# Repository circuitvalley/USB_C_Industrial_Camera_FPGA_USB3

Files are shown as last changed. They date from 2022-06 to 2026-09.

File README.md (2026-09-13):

### USB C industrial camera with Interchangeable C mount Lens, Interchangeable MIPI Sensor with Lattice Crosslink NX FPGA Cypress FX3 USB 3.0 controller

> [!TIP]
> **New Version CHC5 Open Source Camera is available.**

<a href="https://github.com/circuitvalley/CHC5_Open_Camera">
OpenSourceCamera
</a>

New CHC5 Github  https://github.com/circuitvalley/CHC5_Open_Camera

## FPGA ISP Pipeline Specifications
MPI CSI receiver ISP has No virtual restriction on supported frame rate or resolution. Tested more than 4K with IMX477 4056x3040. Can do 8K with around 30FPS or even higher than that as long as FPGA is fast enough for needed frame rate and FPGA/Board has enough memory to be able to store minimum 4 Line worth of pixels. Output Clock is independent of MIPI clock.
Easily Portable code to Xilinx or any other FPGA, No Vendor specific components has been used except for the PHY itself which can be replaced by other vendor's DDR phy and Embedded Block RAM. Only Debayer/Demosaic and Output reformatter need Block RAM. Block ram can also be replaced vendor's RAM.
Auto detection of RAW pixel width supporting different camera sensors and sensor modes without FPGA reconfiguration. 

Speed
------------
- Supports MIPI bus clock 900Mbitsps Per lane with upto 4 Lanes, Total 3.6Gbitsps Sensor bit stream, Has been Tested upto 900Mbitsps with 8x Gear.</br>
- Pixel Processing pipeline with 2,4 or 8 Pixel per clock can reach more than 110Mhz with Lattice Crosslink-NX LIFCL-40 High Speed, So basically Can process upto 880 MegaPixels per second. With this can reach Around 120FPS with 4K resolution and around 30 FPS with 8K. Or even 3000 FPS with 640 x 480 as long as Camera and MIPI Wire allows. With Different Faster FPGA speed will be more.</br>
- FPGA Oputput Pipeline is decoupled from MIPI clock, runs on output clock, It feeds into Cypress FX3 32bit GPIF can do Max 160Mhz. Cyress FX3's specs limits max GPIF clock to 100Mhz.</br>

Configurability
------------
- **Selectable max RAW pixel width**</br>
FPGA Design is configurable with parameters to support pixel depth from RAW10 to RAW14 or Virtually  any bit depth even 16bit RAW when it becomes a MIPI Specs. Parameter specify maximum pixel width that is supported while module auto detect package type at runtime with RAW14 selected as max pixel width, RAW10, RAW12 and RAW14 will be automatically detected and processed</br>
- **Selectable number of MIPI lanes**</br>
With just definition of Parameter value number of lane is also configurable between 2 or 4 MIPI lanes.</br>
- **Selectable Pipeline Size**</br>
Pipeline is Configurable with a parameter to Process 2,4 or 8 Pixel.  2 Pixel Per Clock is only available with 2 Lane MIPI, while 8 Pixel Per Clock is only available with 4 Lanes.</br>
- **Selectable MIPI Gear Ratio**</br>
User can select weather to operate MIPI/DDR phy in 16x or 8x Gear ratio. Most DDR/MIPI phy supports 8x Gear while few do support 16x gear.</br>
Block RAM and DDR PHY IPs need to be manually regenerated if Gear, pixel width , lane or PPC is changed.</br>
- **Selectable MIPI continuous clock mode**</br>
User and select between MIPI clock lp based Frame sync or Frame start and frame stop packt based frame sync. Some MIPI cameras do not support going to LP mode while frame blank occur, With this option user can enable Frame Start and Frame stop detection, to have a frame sync.
- **Selectable ROM based Sample Generator**</br>
For ISP debuging ROM based sample generator can be activated. Two ROM lines are there have both even and odd line to full image test.

Tests 
------------
IMX477
------------
- 4 Lane 12 bit IMX477</br>
4056x3040  15 FPS Full Sensor</br>
2028x1520  60 FPS Full Sensor Binned 2x2</br> 
2028x1080  100 FPS</br>

- 4 Lane 10 bit IMX477</br>
1332x990  150 FPS Binned 4x4</br>
640x480   400 FPS Binned 4x4</br>
640x128   2400 FPS Binned 4x4</br>

- 2 Lane 12 bit IMX477</br>
4056x3040  10 FPS Full Sensor</br>
2028x1520  35 FPS Full Sensor Binned 2x2</br> 
2028x1080  50 FPS</br>

- 2 Lane 10 bit IMX477</br>
1332x990  100 FPS Binned 4x4</br>
640x480   200 FPS Binned 4x4</br>
640x128   1200 FPS Binned 4x4</br>

IMX219
------------
- 4 Lane 10 bit IMX219</br>
3280x2464 30 FPS</br>
1280x720  240 FPS</br>
1920x1080 120 FPS</br>
640x480   400 FPS</br>
640x128   1300 FPS</br>
640x80    2000 FPS</br>

- 2 Lane 10 bit IMX219</br>
3280x2464 15 FPS</br>
1280x720  60 FPS</br>
1280x720  120 FPS</br>
1920x1080 60 FPS</br>
640x480   30 FPS</br>
640x480   200 FPS</br>
640x128   600 FPS</br>
640x80    900 FPS</br>

IMX290/IMX327/IMX462
------------
- 4 Lane 12 bit</br>
1280x720  120 FPS</br>
1920x1080 120 FPS</br>

- 2 Lane 12 bit</br>
1280x720  60 FPS</br>
1920x1080 60 FPS</br>

<a href="https://www.youtube.com/watch?v=dwXs9RB6uD0">
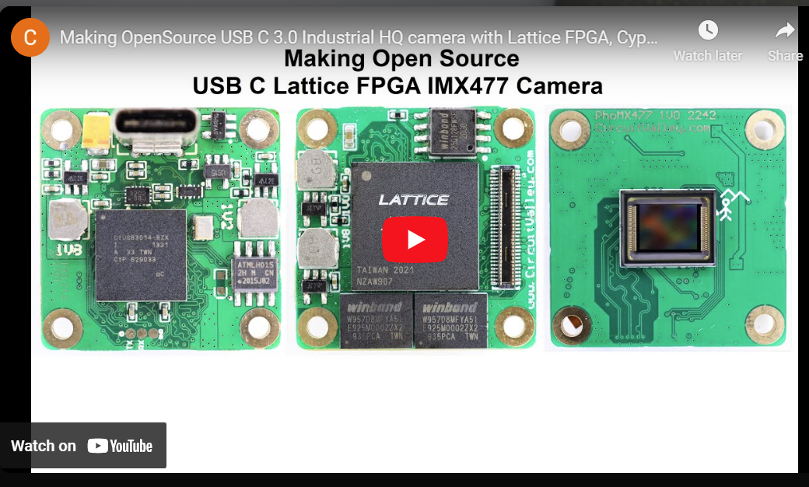
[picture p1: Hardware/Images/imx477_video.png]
IMX219

</a>

#### Project Blog post 
https://www.circuitvalley.com/2022/06/pensource-usb-c-industrial-camera-c-mount-fpga-imx-mipi-usb-3-crosslinknx.html

Shield: [][cc-by]

This work is licensed under a [Creative Commons Attribution 4.0 International
License][cc-by].

[][cc-by]

[cc-by]: http://creativecommons.org/licenses/by/4.0/
[cc-by-image]: https://i.creativecommons.org/l/by/4.0/88x31.png
[cc-by-shield]: https://img.shields.io/badge/License-CC%20BY%204.0-lightgrey.svg



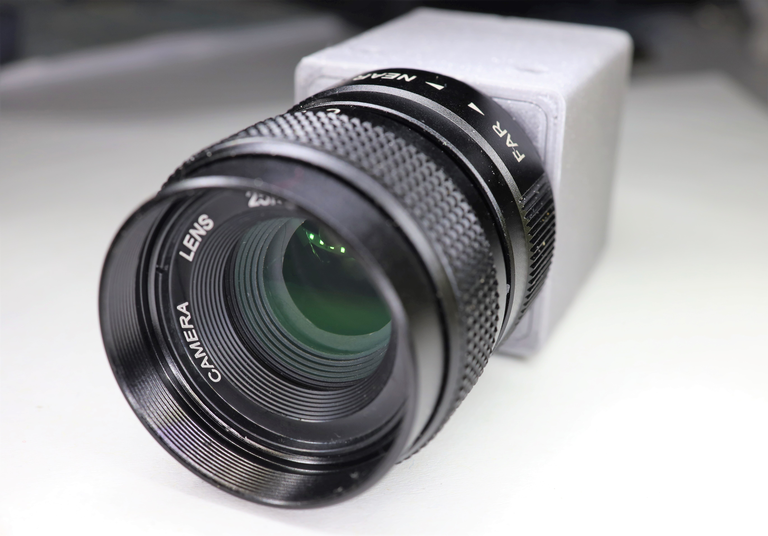
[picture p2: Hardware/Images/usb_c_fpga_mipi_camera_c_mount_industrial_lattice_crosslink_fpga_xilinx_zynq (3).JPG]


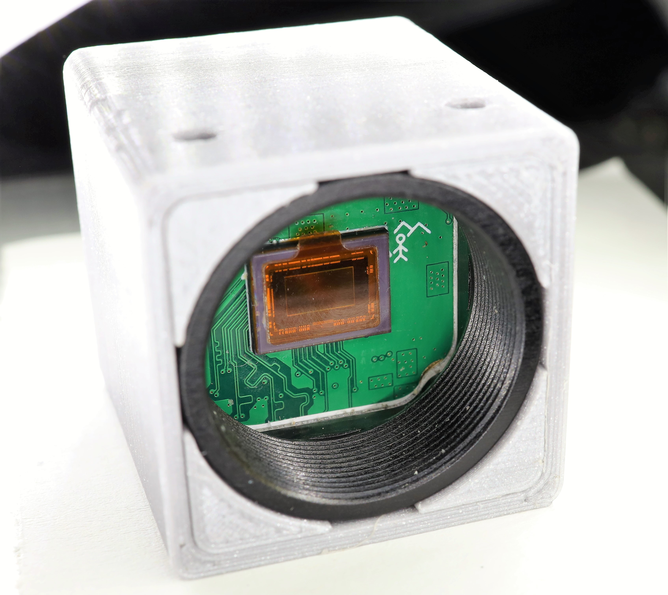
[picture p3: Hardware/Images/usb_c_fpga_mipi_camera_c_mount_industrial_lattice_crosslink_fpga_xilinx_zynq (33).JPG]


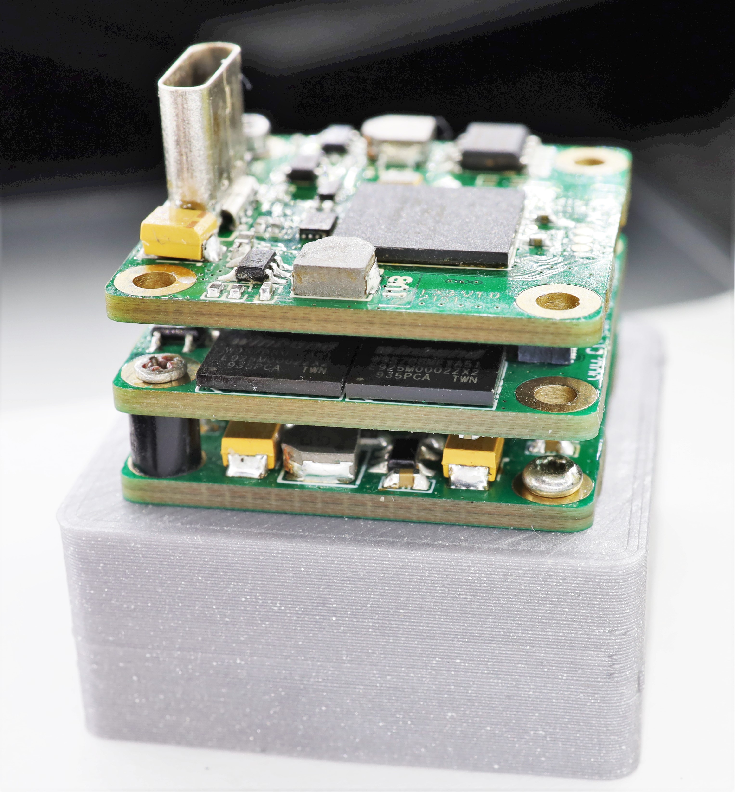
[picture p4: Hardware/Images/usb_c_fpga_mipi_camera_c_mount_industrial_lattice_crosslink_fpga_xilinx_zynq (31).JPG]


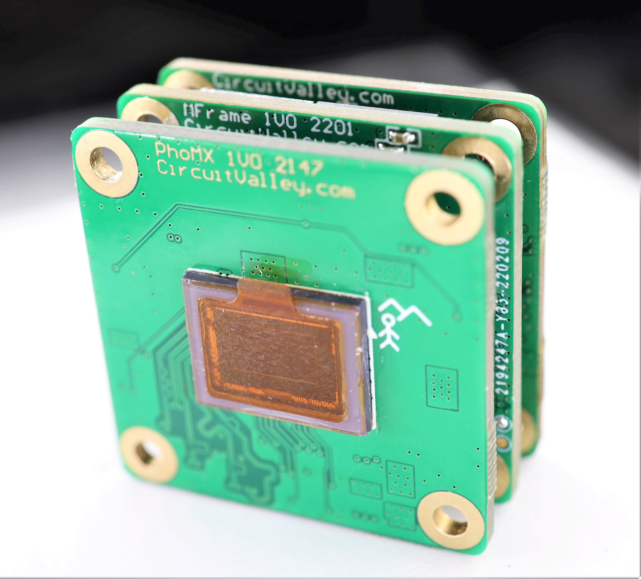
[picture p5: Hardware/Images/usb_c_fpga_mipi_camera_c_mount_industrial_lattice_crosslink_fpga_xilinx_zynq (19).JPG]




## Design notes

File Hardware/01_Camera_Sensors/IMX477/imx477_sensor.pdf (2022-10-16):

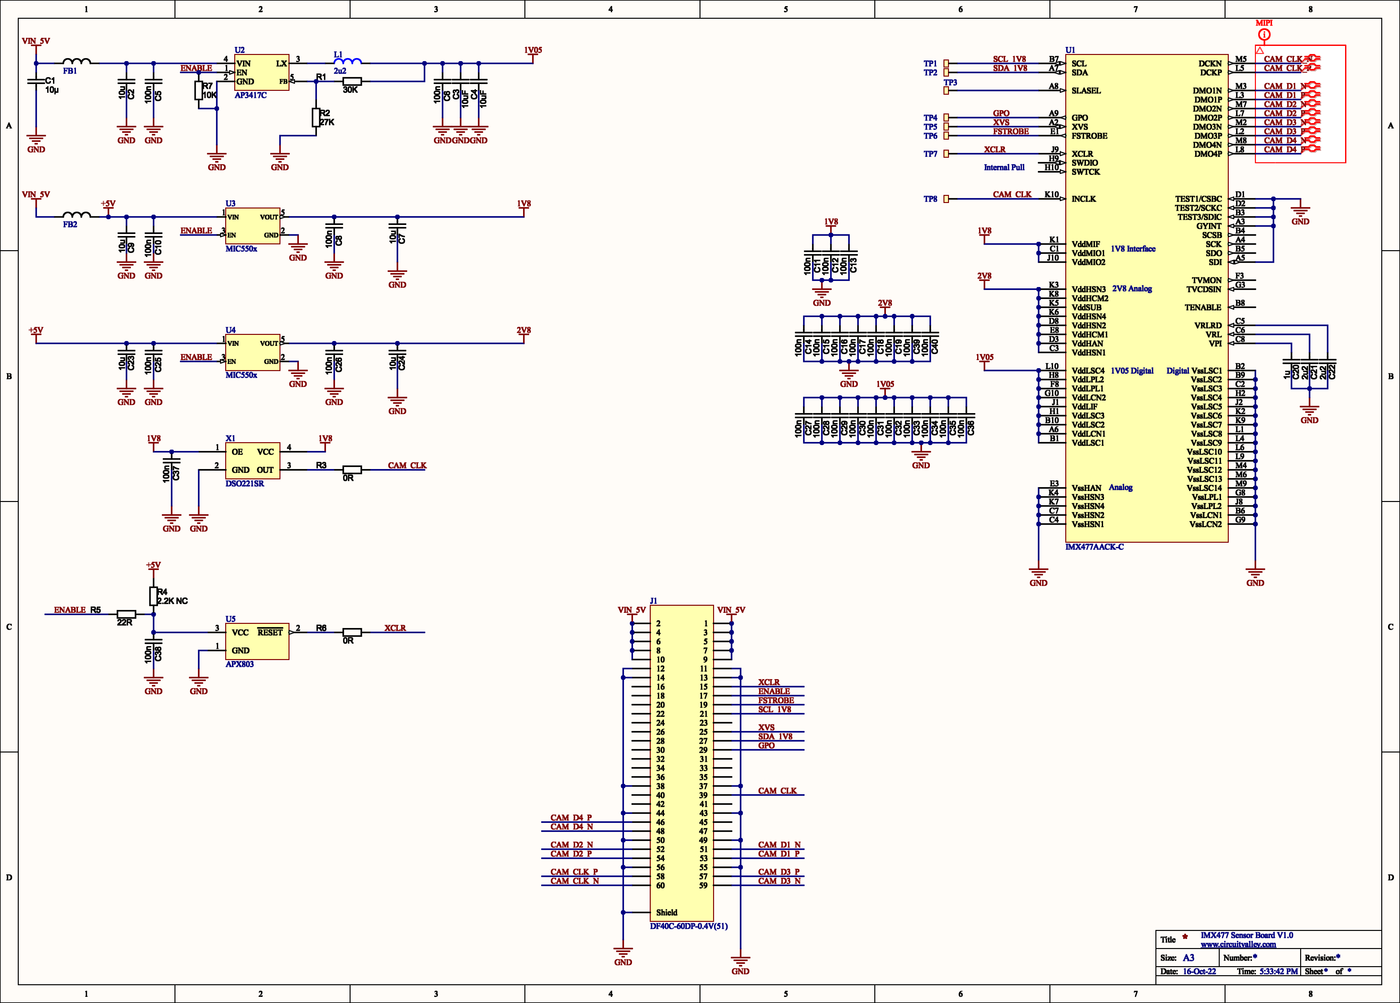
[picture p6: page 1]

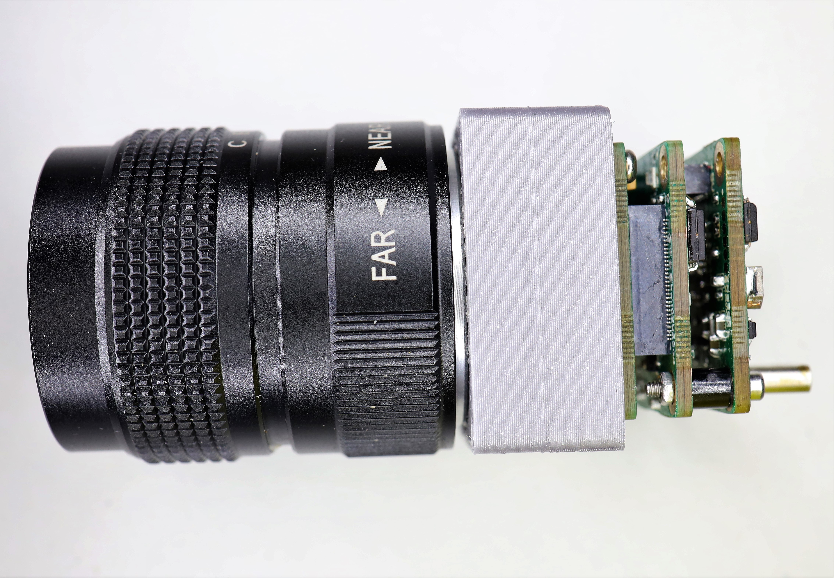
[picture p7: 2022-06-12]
Hardware/Images/usb_c_fpga_mipi_camera_c_mount_industrial_lattice_crosslink_fpga_xilinx_zynq (6).JPG

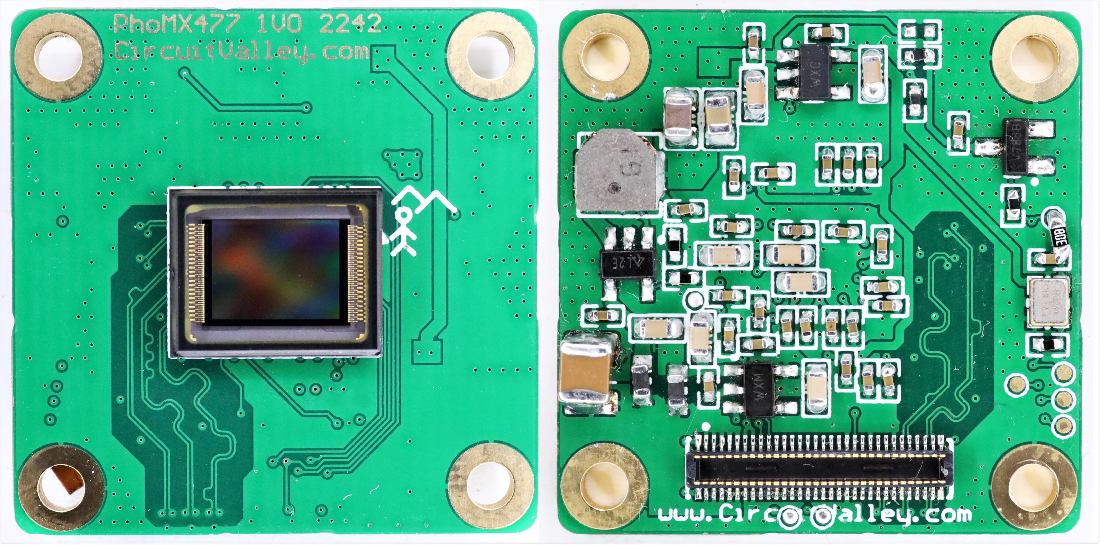
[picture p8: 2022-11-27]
Hardware/Images/custom IMX477 Sensor with FPGA.JPG

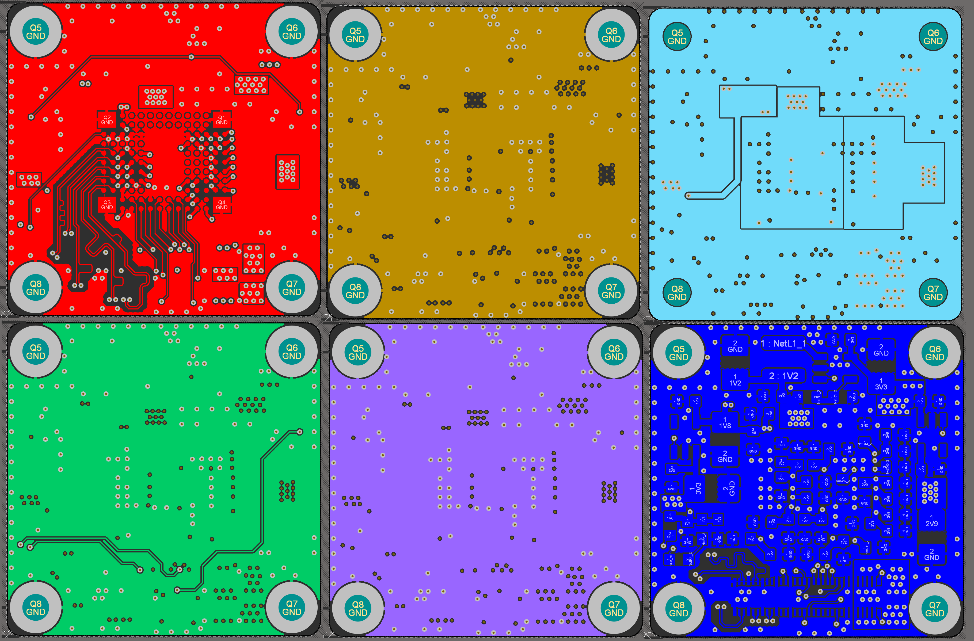
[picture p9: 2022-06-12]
Hardware/Images/IMX290_sensor_PCB.png

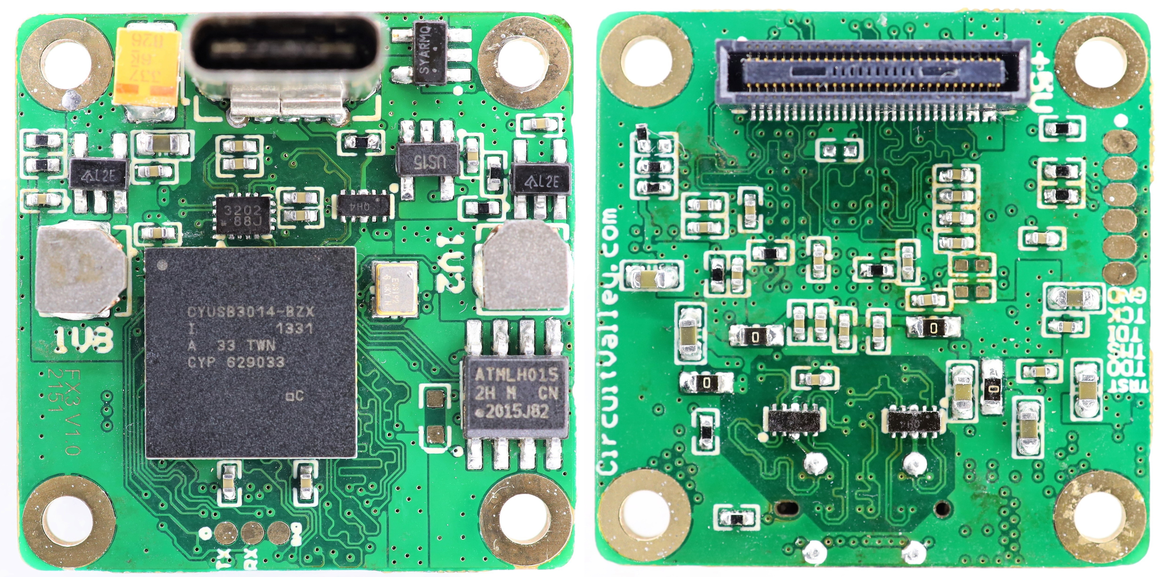
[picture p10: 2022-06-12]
Hardware/Images/usb_c_fpga_mipi_camera_c_mount_industrial_lattice_crosslink_fpga_xilinx_zynq (12)2.JPG

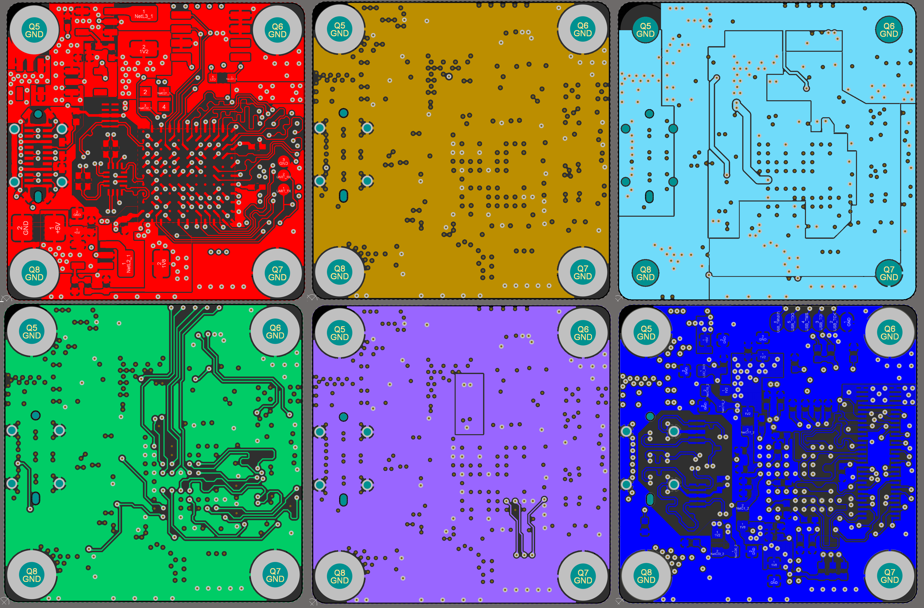
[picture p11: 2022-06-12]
Hardware/Images/fx3_PCB.png

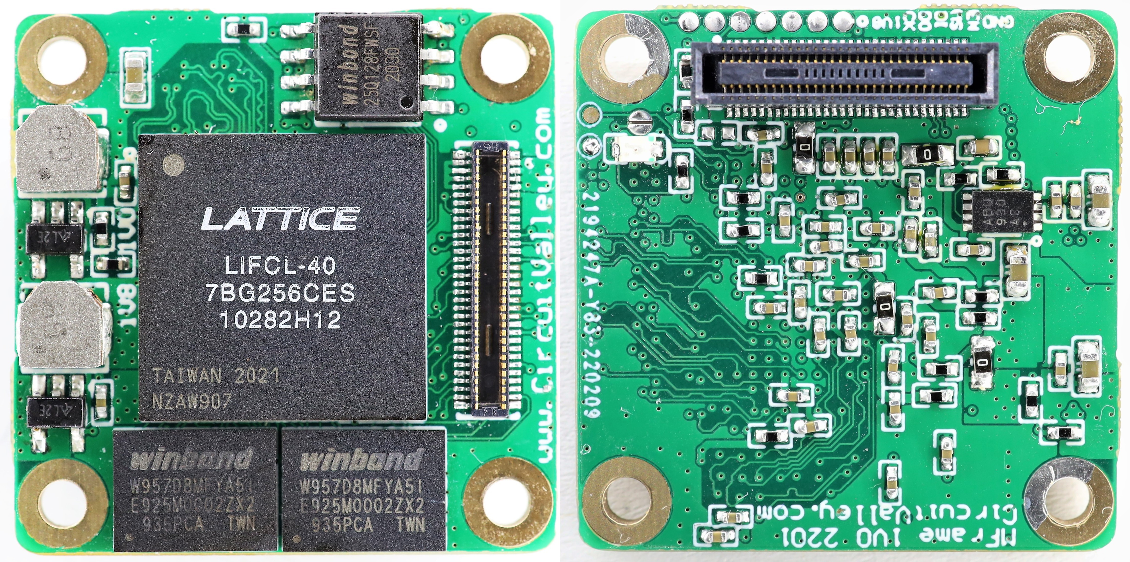
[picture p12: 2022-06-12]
Hardware/Images/usb_c_fpga_mipi_camera_c_mount_industrial_lattice_crosslink_fpga_xilinx_zynq (14)1.JPG

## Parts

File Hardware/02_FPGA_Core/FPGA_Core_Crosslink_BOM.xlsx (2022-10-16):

Comment | Description | Designator | Footprint | Quantity | QTY1 | QTY 10 | QTY100 | QTY500 | Price 1 | Price 10 | Price 100 | Price 500
100n | Capacitor SMD Cer 100nF 10% 16V X7R 0402 | C1, C3, C4, C5, C6, C7, C8, C9, C11, C12, C13, C14, C15, C16, C17, C18, C19, C20, C21, C22, C23, C24, C26, C27, C28, C29, C30, C31, C32, C33, C38, C39, C40, C42, C43, C44, C45, C? | CAPC1005N | 38 | 0.1 | 0.025 | 0.021 | 0.015 | 3.8 | 0.95 | 0.798 | 0.57
1uf | Capacitor SMD Cer 10nF 10% 16V X7R 0402 | C2 | CAPC1005N | 1 | 0.1 | 0.041 | 0.033 | 0.024 | 0.1 | 0.041 | 0.033 | 0.024
10uF | Capacitor SMD Cer 10uf 5% 50V NP0 0603 | C34, C35, C36, C37 | CAPC1608N | 4 | 0.29 | 0.131 | 0.111 | 0.079 | 1.16 | 0.524 | 0.444 | 0.316
Ferrite |  | FB1, FB2, FB3, FB4 | INDC1608N | 4 | 0.1 | 0.068 | 0.037 | 0.034 | 0.4 | 0.272 | 0.148 | 0.136
DF40C-60DP-0.4V(51) | Samtec 0.5mm 60 pin Connector | J1 | DF40C-60DP-0.4V | 1 | 1.4 | 1.12 | 1.07 | 0.871 | 1.4 | 1.12 | 1.07 | 0.871
SMD Jumper | SMD Jumper | J2 | SMD_Jumper | 1 | 0 | 0 | 0 | 0 | 0 | 0 | 0 | 0
DF40HC(4.0)-60DS-0.4V(51) | Hiros 60 pin Connector | J3 | DF40HC(4.0)-60DS-0.4V(51) | 1 | 1.81 | 1.51 | 1.41 | 1.18 | 1.81 | 1.51 | 1.41 | 1.18
2u2 |  | L2, L3 | FDSD0420-H-2R2M | 2 | 0.65 | 0.527 | 0.415 | 0.349 | 1.3 | 1.054 | 0.83 | 0.698
TestPoint | SMD Test Point | L4, L7 | SMD_test_point | 2 |  |  |  |  | 0 | 0 | 0 | 0
Red | LED 0603 SMD Hyper Red 630nm 220mcd 20mA | LED2 | LED-0603-RED | 1 | 0.16 | 0.151 | 0.142 | 0.105 | 0.16 | 0.151 | 0.142 | 0.105
Header |  | P1 | SMD_Solder_points_1.27_x7 | 1 | 0 | 0 | 0 | 0 | 0 | 0 | 0 | 0
Thick Film | Resistor SMD chip 0.063W 5% 0402 | R1, R2, R3, R4, R5, R6, R7, R8, R9, R12, R13, R15, R16, R23, R24, R25, R26, R27, R? | RESC1005N | 19 | 0.1 | 0.07 | 0.029 | 0.013 | 1.9 | 1.33 | 0.551 | 0.247
LIFCL-40-9BG256C | FPGA CorsslinkNX LIFCL-40-9BG256C | U1 | Lattice_256_CABGA | 1 | 65.95 | 57.42 | 55.28 | 55.28 | 65.95 | 57.42 | 55.28 | 55.28
W957D8MFYA5I | HyperRAM 16Mx8 | U2, U21 | TFBGA24 | 2 | 3.93 | 3.11 | 3.1 | 2.99 | 7.86 | 6.22 | 6.2 | 5.98
MCP1725-ADJE/MC | LDO | U3 | DFN8_3x2 | 1 | 0.72 | 0.711 | 0.541 | 0.54 | 0.72 | 0.711 | 0.541 | 0.54
SST26WF064C / MX25U12832F | Flash 128Mbit for Lattice FPGA | U4 | SOP8 | 1 | 2.07 | 1.85 | 1.8 | 1.8 | 2.07 | 1.85 | 1.8 | 1.8
AP3417C |  | U7, U11 | SOT23-5 | 2 | 0.5 | 0.274 | 0.185 | 0.157 | 1 | 0.548 | 0.37 | 0.314
PCB |  |  |  | 1 | 10 | 5 | 1 | 0.29 | 10 | 5 | 1 | 0.29
 |  |  |  |  |  |  |  |  | 99.63 | 78.701 | 70.617 | 68.351
 |  |  |  |  | These are mouser price EUR, So improvements possible.

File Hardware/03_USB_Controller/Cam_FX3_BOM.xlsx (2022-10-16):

Comment | Description | Designator | Footprint | Quantity | QTY1 | QTY 10 | QTY100 | QTY500 | Price 1 | Price 10 | Price 100 | Price 500
100n | Capacitor SMD Cer 100nF 10% 16V X7R 0402 | C1, C2, C3, C4, C5, C6, C7, C8, C9, C10, C11, C12, C13, C14, C15, C17, C19, C20, C21, C22, C23, C24, C26, C27, C28, C29, C30, C42, C87, C88, C89, C90 | CAPC1005N | 32 | 0.1 | 0.025 | 0.021 | 0.015 | 3.2 | 0.8 | 0.672 | 0.48
10nF | Capacitor SMD Cer 10nF 10% 16V X7R 0402 | C18 | CAPC1005N | 1 | 0.1 | 0.041 | 0.033 | 0.024 | 0.1 | 0.041 | 0.033 | 0.024
10µ | Capacitor SMD Tantalum 10uF 20% 6.3V 1210 | C25 | CAPMP3528X210N | 1 | 0.37 | 0.277 | 0.198 | 0.131 | 0.37 | 0.277 | 0.198 | 0.131
10uF | Capacitor SMD Cer 560pF 5% 50V NP0 0603 | C34, C35, C36, C37, C38, C39, C40 | CAPC1608N | 7 | 0.29 | 0.131 | 0.111 | 0.079 | 2.03 | 0.917 | 0.777 | 0.553
Ferrite |  | FB1, FB2, FB3, FB4 | INDC1608N | 4 | 0.1 | 0.068 | 0.037 | 0.034 | 0.4 | 0.272 | 0.148 | 0.136
DF40HC(4.0)-60DS-0.4V(51) | Hiros 60 pin Connector | J1 | DF40HC(4.0)-60DS-0.4V(51) | 1 | 1.81 | 1.51 | 1.41 | 1.18 | 1.81 | 1.51 | 1.41 | 1.18
USB C Connector | USB C connector | J2 | 10132328-10001LF | 1 | 3.64 | 3.29 | 2.92 | 2.55 | 3.64 | 3.29 | 2.92 | 2.55
2u2 |  | L2, L3 | FDSD0420-H-2R2M | 2 | 0.65 | 0.527 | 0.415 | 0.349 | 1.3 | 1.054 | 0.83 | 0.698
Red | LED 0603 SMD Hyper Red 630nm 220mcd 20mA | LED1 | LED-0603-RED | 1 | 0.16 | 0.151 | 0.142 | 0.105 | 0.16 | 0.151 | 0.142 | 0.105
Header 6 | Header, 6-Pin | P2 | SMD_Solder_points_1.27 | 1
Header 3 | Header, 3-Pin | P4 | SMD_3Solder_points_1.27 | 1
6.04K | Resistor SMD chip 3.3k Ohm 0.063W 5% 0402 | R1, R6 | RESC1005N | 2 | 0.1 | 0.07 | 0.029 | 0.013 | 0.2 | 0.14 | 0.058 | 0.026
Thick Film | Resistor SMD chip 3.3k Ohm 0.063W 5% 0402 | R2, R3, R4, R5, R8, R9, R10, R11, R12, R13, R14, R15, R16, R17 | RESC1005N | 14 | 0.1 | 0.07 | 0.029 | 0.013 | 1.4 | 0.98 | 0.406 | 0.182
AP3417C |  | U7, U11 | SOT23-5 | 2 | 0.5 | 0.274 | 0.185 | 0.157 | 1 | 0.548 | 0.37 | 0.314
NCP360SNT1G | USB Overvoltage Protection | U12 | SOT23-5 | 1 | 0.87 | 0.763 | 0.593 | 0.463 | 0.87 | 0.763 | 0.593 | 0.463
CYUSB3014-BZXC | EZ-USB(R) FX3: SuperSpeed USB Controller, 512 KB, 60 I/Os, 0 to 70 degC, 121-Pin FBGA (BZX121) | U13 | CYP-BZX121 | 1 | 38.88 | 35.878 | 30 | 29 | 38.88 | 35.878 | 30 | 29
SP3010-04UTG | ESD Protection | U14, U15, U18 | uDFN-10 | 3 | 0.87 | 0.781 | 0.609 | 0.397 | 2.61 | 2.343 | 1.827 | 1.191
AT24CM02 | 2Mbit I2C EEPROM | U16 | SOIC8 | 1 | 3.44 | 3.13 | 3.06 | 2.73 | 3.44 | 3.13 | 3.06 | 2.73
HD3SS3202 | USB 3.0 Mux | U17 | UQFN-16 | 1 | 1.35 | 1.22 | 1.16 | 0.949 | 1.35 | 1.22 | 1.16 | 0.949
MIC550x |  | U20 | SOT23-5 | 1 | 0.16 | 0.159 | 0.12 | 0.12 | 0.16 | 0.159 | 0.12 | 0.12
ECS-192-7-36B-CKY-TR | Crystal Oscillator | X1 | Active Oscillator 2520 | 1 | 0.5 | 0.383 | 0.334 | 0.316 | 0.5 | 0.383 | 0.334 | 0.316
PCB |  |  |  | 1 | 10 | 5 | 1 | 0.29 | 10 | 5 | 1 | 0.29
 |  |  |  |  |  |  |  |  | 60.57 | 50.695 | 39.07 | 35.686
 |  |  |  |  | These are mouser price in EUR , So improvements possible.

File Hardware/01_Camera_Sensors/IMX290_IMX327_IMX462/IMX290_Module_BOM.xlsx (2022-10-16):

Comment | Description | Designator | Footprint | LibRef | Quantity | Qty1 | Qty10 | QTY100 | QTY500 | Price 1 | Price 10 | Price 100 | Price 500
10u | Capacitor SMD Tantalum 10uF 20% 6.3V 1210 | C1, C2, C6, C7, C11 | CAPMP3528X210N | CAPT_47u_1210_6V3 | 5 | 0.37 | 0.277 | 0.198 | 0.131 | 1.85 | 1.385 | 0.99 | 0.655
100n | Capacitor SMD Cer 100nF 5% 50V NP0 0603 | C3, C4, C5, C8, C9, C12, C13, C14, C15, C16, C17, C18, C19, C20, C21, C22, C23, C24, C25, C26 | CAPC1608N | CAPC_10p_0603_NP0_1%_50V | 20 | 0.1 | 0.041 | 0.033 | 0.024 | 2 | 0.82 | 0.66 | 0.48
10u | Capacitor SMD Cer 10uF 5% 50V NP0 0603 | C10, C29, C31, C32, C33, C34, C35, C36, C37, C39, C40 | CAPC1608N | CAPC_10p_0603_NP0_1%_50V | 11 | 0.1 | 0.041 | 0.033 | 0.024 | 1.1 | 0.451 | 0.363 | 0.264
10n | Capacitor SMD Cer 10nF 5% 50V NP0 0603 | C27 | CAPC1608N | CAPC_10p_0603_NP0_1%_50V | 1 | 0.1 | 0.041 | 0.033 | 0.024 | 0.1 | 0.041 | 0.033 | 0.024
0.22uf | Capacitor SMD Cer 220nF 5% 50V NP0 0603 | C41 | CAPC1608N | CAPC_10p_0603_NP0_1%_50V | 1 | 0.1 | 0.041 | 0.033 | 0.024 | 0.1 | 0.041 | 0.033 | 0.024
1uf | Capacitor SMD Cer 1uF 5% 50V NP0 0603 | C42, C43, C44 | CAPC1608N | CAPC_10p_0603_NP0_1%_50V | 3 | 0.1 | 0.041 | 0.033 | 0.024 | 0.3 | 0.123 | 0.099 | 0.072
DF40C-60DP-0.4V(51) | Samtec 0.5mm 60 pin Connector | J1 | DF40C-60DP-0.4V | LSHM-130-xx | 1 | 1.4 | 1.12 | 1.07 | 0.871 | 1.4 | 1.12 | 1.07 | 0.871
2u2 |  | L1 | TAIYO_NRS4018T2R2MDGJ | inductor_smd | 1 | 0.65 | 0.527 | 0.415 | 0.349 | 0.65 | 0.527 | 0.415 | 0.349
Thick Film | Resistor SMD chip 0.0 Ohm 0.1W 0603 | R1, R2, R3, R4 | RESC1608N_ZERO | RES_0R_0603 | 4 | 0.1 | 0.07 | 0.029 | 0.013 | 0.4 | 0.28 | 0.116 | 0.052
IMX290LQR-C | Sony Color Image senosr | U1 | IMX290LQR-C | IMX290LQR-C | 1 | 20 | 20 | 20 | 20 | 20 | 20 | 20 | 20
AP3417C |  | U2 | SOT23-5 | AP3417C | 1 | 0.5 | 0.274 | 0.185 | 0.157 | 0.5 | 0.274 | 0.185 | 0.157
MIC550x |  | U3, U4 | SOT23-5 | MIC550x | 2 | 0.16 | 0.159 | 0.12 | 0.12 | 0.32 | 0.318 | 0.24 | 0.24
DSO221SR | Active Oscillator_2520 | X1 | Active Oscillator 2520 | Oscillator_2520 | 1 | 2.03 | 1.94 | 1.63 | 1.63 | 2.03 | 1.94 | 1.63 | 1.63
PCB |  |  |  |  | 1 | 10 | 5 | 1 | 0.29 | 10 | 5 | 1 | 0.29
 |  |  |  |  |  |  |  |  |  | 40.75 | 32.32 | 26.834 | 25.108
 |  |  |  |  |  | These are mouser price EUR, So improvements possible.

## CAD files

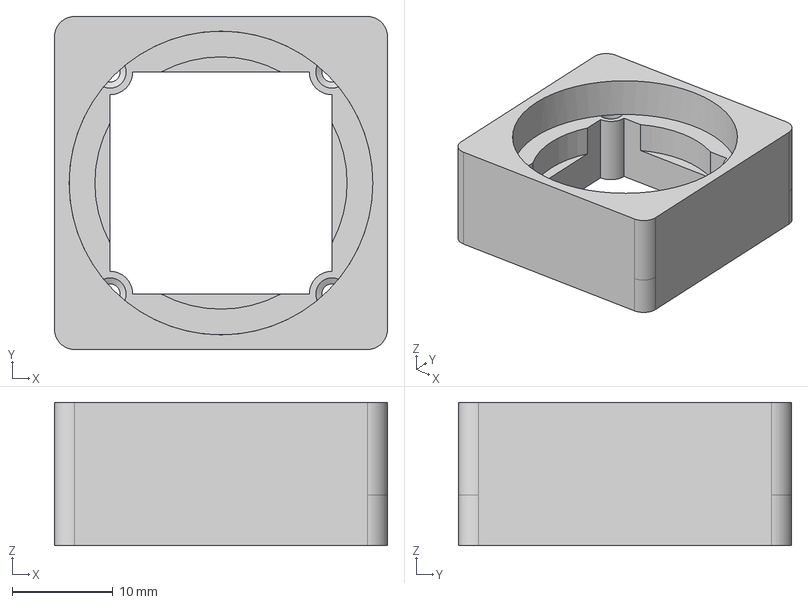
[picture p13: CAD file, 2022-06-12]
Hardware/Encolosure_Camera_mount/Lens_mount/C mount v1.step
33.0 x 33.0 x 14.2 mm

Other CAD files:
Hardware/Encolosure_Camera_mount/Lens_mount/C mount v1.f3d

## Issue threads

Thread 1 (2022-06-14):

Congratulations to the board(s)!

sandorkonya, 2022-06-14:
What is the current approximate bill of materials?

rajhlinux, 2022-07-24:
Yes would also like to congratulate such remarkable fully custom made camera.

It's impossible to buy bare bone Sony image sensors as a regular hobbyist consumer, can only buy Sony image sensors as a module.
Wonder where can one buy the buy bare bone Sony image sensors...

circuitvalley, 2022-07-26:
Currently i am preparing BOM with approximate price. So check back soon.

Yes bare sensors are hard to find i found my sensors from online retails specially Chinese websites. Or alternately you could get IMX477 sensors from  Raspberry Pi camera board

circuitvalley, 2022-10-09:
BOM cost is as follows with no tax and no shipping
FX3 Board
QTY 1      QTY10      QTY 500
60             50              35
Crosslink NX
QTY 1      QTY10       QTY500
101           78             68
IMX290/462 Camera
QTY 1       QTY 10      QTY500
41             32              25

Total for Just PCBs
QTY 1           QTY10             QTY500
202 EUR       170 EUR          128 EUR

Enclosure and lens would be additional

Closed 2022-10-09.

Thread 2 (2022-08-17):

Hey, where can I buy your open source LIFCL-40-9BG256C chip?

lookembedded, 2022-08-17:
Hey, where can I buy your open source LIFCL-40-9BG256C chip? Can you share it with me? Or sell me one of your samples
It would be greatful if you could help me :)
Best regards,
Zhang Bo

circuitvalley, 2022-08-17:
Just few weeks ago they were in stock at mouser, Right now i think they are not in stock anywhere. If you really want to get started with LIFCL-40 there are devboards i think still available.
Regards

lookembedded, 2022-08-18:
Thanks for sharing the info. I don't want to go to the deveboard direction. I really like your 6-layers designed board style. Is that possible that you share one finished such camera with me. I would like to pay the cost.

circuitvalley, 2022-08-18:
If feel you can possibly drop an Email. I think i can possibly find a solution for you.

lookembedded, 2022-08-18:
Thanks. This is my email: jxh832027@gmail.com. Looking forward to your email.

circuitvalley, 2022-08-19:
Your Email appears to be incorrect.

lookembedded, 2022-08-19:
sorry，my bad. It is jxh831027@gmail.com

SinanAkkoyun, 2023-01-13:
Hi, I highly appreciate the work and nice design you have done!
Would it be ok for you if you could please also build me this camera? I will pay all costs and fees.

My mail is sinan@akkoyun.xyz

Thank you very much.
Best Regards,
Sinan

lookembedded, 2023-01-15:
Sorry, it's not mine. I just retweeted it. It's from a fan in Germany

| |
张博
|
|
***@***.***
|
---- Replied Message ----
| From | ***@***.***> |
| Date | 1/13/2023 09:59 |
| To | ***@***.***> |
| Cc | bo ***@***.***> ,
***@***.***> |
| Subject | Re: [circuitvalley/USB_C_Industrial_Camera_FPGA_USB3] Hey, where can I buy your open source LIFCL-40-9BG256C chip? (Issue #2) |

Hi, I highly appreciate the work and nice design you have done!
Would it be ok for you if you could please also build me this camera? I will pay all costs and fees.

My mail is ***@***.***

Thank you very much.
Best Regards,
Sinan

—
Reply to this email directly, view it on GitHub, or unsubscribe.
You are receiving this because you authored the thread.Message ID: ***@***.***>

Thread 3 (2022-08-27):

ECP5 supported?

francis2tm, 2022-08-27:
Hello,
Amazing project. I was wondering if it is possible to use this with an ECP5 FPGA?

circuitvalley, 2022-10-09:
There are no specific restriction in place that will prevent design from getting used with ECP5 FPGA , or any other FPGA.
ECP5 Does not have hard MIPI phy, So you would need to use soft phy, Which is basically same thing. I have already demonstrated using Soft mipi phy with Lattice MachXO3 FPGA.

Closed 2022-10-09.

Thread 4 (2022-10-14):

Bill of Material and BOM Cost

cliffchar, 2022-10-14:
Do you have Bill of Material and also have any idea how much is BOM cost?

circuitvalley, 2022-10-14:
BOM excel list are present in the under hardware in the repo.

BOM cost is as follows with no tax and no shipping , these are mouser/digikey prices , so there is improvement possible
FX3 Board
QTY 1 , QTY10 QTY 500
60 EUR , 50 EUR , 35 EUR
Crosslink NX
101 EUR , 78 EUR , 68 EUR
IMX290/462 Camera
41 EUR , 32 EUR , 25 EUR

Total for Just PCBs
QTY 1 , QTY10 , QTY500
202 EUR , 170 EUR , 128 EUR

Enclosure and lens would be additional

Closed 2022-10-14.

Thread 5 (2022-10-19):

Future support for larger sensors?

edward-io, 2022-10-19:
Really cool project! Theoretically, could the camera support
 4/3" sensors os larger? For example: IMX269, IMX272, IMX271, IMX571.

circuitvalley, 2022-10-19:
There is no specific limit on sensor size, it's just matter of making needed adjust to enclosure, and make a suitable lens mount. As long as camera has MIPI CSI interface my design could be used as is.
I have just made commit with IMX477 files.

Regards

circuitvalley, 2022-10-19:
For future plans, I will possibly make camera with IMX294 as I have designs ready with that sensor.

circuitvalley, 2022-10-19:
Do you have any idea where one could possibly find sensor to buy any of your IMX269, IMX272, IMX271, IMX571.

Closed 2022-10-19.

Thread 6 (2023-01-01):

OotoPart BOMs?

jleppert, 2023-01-01:
Thanks for publishing this amazing project! I am putting together an OctoPart BOMs for the boards, can you kindly review this one for FPGA board BOM?

https://octopart.com/bom-tool/CdZ11cSl

Thank you!

circuitvalley, 2023-01-14:
Thank you for your time. I am looking into the it.

circuitvalley, 2023-02-04:
Appears to be all correct

Closed 2023-02-04.

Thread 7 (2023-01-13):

some schematic is missing

james2002chen, 2023-01-13:
In the FPGA_core project，two 40 pin dense connectors J1 and J2 appear on the PCB drawing，but there's no J1 or J2 on any of the schematic currently published. Please check if files under \Hardware\02_FPGA_Core\PCB_Source is complete

james2002chen, 2023-01-13:
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
from the component class, it can be told that is missing file is named "camera.SchDoc"

circuitvalley, 2023-01-14:
Thank you for pointing, File has be added and and fixed  issue with commit #2df2c166f4f118be3986a7159f8ee61677012df9

Closed 2023-01-14.

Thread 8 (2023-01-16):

resistor values in BOM are incorrect

james2002chen, 2023-01-16:
The resistor values in all the 3 BOM files are incorrect.

For example, in \Hardware\01_Camera_Sensors\IMX290_IMX327_IMX462\IMX290_Module_BOM.xlsx
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
All the four resistors are annotated as "0 ohm", which doesn't match with the schematic:
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
That's also the case in FPGA_bom and usbc_bom, causing confusion during the assembly.

Please change the Comment field of the resistors from "Thick Film" to "=Value", and update all three BOM files.
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

circuitvalley, 2023-02-04:
Values are correct in schematic. Please refer to schematics. You can put values into xls files and create a pull request

Closed 2023-02-04.

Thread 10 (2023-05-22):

Faild to use  HW-USBN-2B tool to programming the FPGA

INDNextHenry, 2023-05-22:
Hi @circuitvalley, I am trying to replicate this great project, but currently I am encountering a burning issue with the FPGA.

I am using the `HW-USBN-2B` programmer to program the `external FLASH`, the connection shown in the figure (GND, JTAG-EN, TMS, TDI, TDO, TCK).
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
But the programming software always reports an error and cannot read the Device's IDCODE. It say `Failed to read the Device's IDCODE`.
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
By checked the hardware connection and found no clue. Please give me suggestions and comments if it is convenient，I appreciate your help!!

INDNextHenry, 2023-05-23:
I used ESP-PROG to complete the programming of the FPGA, but the official `HW-USBN-2B` does not work, I don't know why.
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

Closed 2023-05-23.

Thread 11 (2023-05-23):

No ENABLE signal to boot the IMX290 sensor from the lattice FPGA

INDNextHenry, 2023-05-23:
Hi @circuitvalley,
After program the fpga and usb3, finnaly I got a another issue, the IMX290 sensor board has no power. **The ENABLE signal was always low level**. I suspect that the fpga program is not normally started from the external flash, but I don't know how to verify this problem.
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
The Cypress FX3 USB3 serial port output log:
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
I think I should be very close to the final success, please help me, Thank you very much!!

INDNextHenry, 2023-05-23:
I think I loaded the `/Cypress_FX3_USB_Firmware/Image/USB_C_FX3_CV.img` was default suit for IMX477. So the IMX290 is not working.

circuitvalley, 2023-05-23:
You can compile img file for IMX290  your self or wait for a while I can provide you a .img file.

Regards

circuitvalley, 2023-05-24:
To fix compile issue, Include correct file in source. and include and exclude correct file in eclipse project as well. look on internet of including or excluding files from eclipse project

INDNextHenry, 2023-05-25:
Hi @circuitvalley
I tried to build a fx3 project, then compile it.
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
It seems to work, then I got some *.img files.
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
Unfortunately I still don't get the ENABLE high signal of the IMX290 board.  The ENABLE signal of the IMX290 board is sent from the lattice FPGA.
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
Although the FPGA programming is successful, I still need to investigate why the ENABLE signal is not enabled.
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
I suspect that the FPGA is not functioning properly, the evidenced is the DONE signal not being pulled low as expected.
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
The LED2 quickly go off.
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

INDNextHenry, 2023-05-25:
The latest status, I directly burn the program into the SRAM of the FPGA, the DONE signal is pulled low, and now the LED2 light is red.
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
However, the USB serial port gives a frame timer timeout warning, I guess because the frequency of the FX3 is set to 400MHZ? and the DMA needs to be set to 32K?
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

INDNextHenry, 2023-06-02:
In a words, I success programmed the fpga, but when power off the FPGA and restart, there is no EBABLE signal to IMX290.

nokiagx, 2023-06-03:
I'm not proficient in FPGA and I can't help you. I'm sorry！

At 2023-06-02 16:59:18, "INDNext_Henry" ***@***.***> wrote:

In a words, I success programmed the fpga, but when power off the FPGA and restart, there is no EBABLE signal to IMX290.

—
Reply to this email directly, view it on GitHub, or unsubscribe.
You are receiving this because you are subscribed to this thread.Message ID: ***@***.***>

Closed 2023-09-18.

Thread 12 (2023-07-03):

Version firmware ENABLE and pinout

rubenl1995, 2023-07-03:
Hi @circuitvalley thanks for your design, it's nice.

I want understand your design and need resolve any questions. I hope your help.

I'm going to use your design with sensor IMX290 but I have watched a change no implemented at pin ENABLE, this pin active XCLR from delay ENABLE in PCB IMX477 but PCB IMX290 active from FPGA. In your firmware, where can I watch this change?

In your sketch FPGA I he watched a pinout different respect your schematic, is possible different version? For example, J12 is DATA_0  but in schematic J12 is D8, it's showed in the next figure:

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

Thanks for your time,
Rubén

circuitvalley, 2023-10-22:
Hello,
Schematic D0 is At J12 , and J11 Has been fixed, These pins are data as long as all 32bit connected you can map them anywhere.
Enable pin  is located on same location, It is driven by FPGA , You can always put a pull up to enable the Camera module permanently.

circuitvalley, 2023-10-22:
Hello,
Schematic D0 is At J12 , and J11 Has been fixed, These pins are data as long as all 32bit connected you can map them anywhere.
Enable pin  is located on same location, It is driven by FPGA , You can always put a pull up to enable the Camera module permanently.

Closed 2023-10-22.

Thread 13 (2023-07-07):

Firmware for imx290 FX3

nzy20000618, 2023-07-07:
Hello, could you please send me the firmware of imx290 of fx3? I want to test the imx290 sensor I bought. Here is my email address: nn1275110583@gmail.com

rubenl1995, 2023-07-07:
Hi friend, I bought the sensor IMX290 but I can't power on camera. FX3 send frame by USB because I can watch by UART but with the application webcamoid not show nothing.

Thnak you!!

nzy20000618, 2023-07-07:
> 嗨，朋友，我买了传感器IMX290，但我无法打开相机电源。FX3 通过 USB 发送帧，因为我可以通过 UART 观看，但使用应用程序网络摄像头不会显示任何内容。
>
> 谢谢你！！

Can your imx290 display images now? Can I add your contact information? You can contact me through my email: nn1275110583@gmail.com

circuitvalley, 2023-08-11:
There are few tips I could give you. How to debug if things are not working for you.Checking FPGA
1. Check fpga if it is outputting pixel clock , lsync and fsync. These signals are the most important if any of the pixel(data) lines are not correct then you will get a bad image but if any one of the Clock, Fsync or Lsync are not found you will get no image. This if any of these signals are not there then it may mean a bad solder joint. You can debug by debug signal from FPGA.
2. Check if FPGA outputs the same number of pixels on every frame. You would either need a Physical counter instrument  or a counter implemented in an FPGA. You need to count the exact number of pixels in a Frame. If FPGA output inconsistent number of byte every frame most UVC viewer will ignore frames, These may meen no image at all or massive drop in frame depending on how inconsistent your bytes are.

Checking FX3

1. FX3 part can be debugged by driving GPIO from GPIF or even C code. Debug frame sync Line sync etc. 

2. To check if you are receiving any data at all from the camera. Then use wireshark with USBPcap to capture USB packets. You can easily find these packets and also count how many bytes FPGA is sending. 

3. All the source files including sensor driver are present in repo. Only the sensor selected is included in the build. EZ USB suite allows you to select and deselect source files. EZ USB is eclipse based, Search on internet how to enable disable source in eclipse.4. If you are having a hard time resetting senor then it can be either permanently held out of reset with pull up or you can check how and which pins FPGA drive for resetting.
Sorry I do not have time for individual image builds. 
Regards

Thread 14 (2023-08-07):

Has anyone successfully reproduced this project?

INDNextHenry, 2023-08-07:
Has anyone successfully reproduced this project? I've been struggling with this project for a long time without success.

The FPGA is programmed, and the fx3 runs successfully (the PC can recognize the usb device), but the image cannot be obtained using webcamod8.8.

I guess there are two reasons: 1. There is a problem with the driver configuration of fx3 and imx219 or imx477. 2. There is a problem with the fpga configuration code.

Hope that someone who has successfully copied can provide suggestions or comments, thank you

circuitvalley, 2023-08-11:
There are few tips I could give you. How to debug if things are not working for you.Checking FPGA
1. Check fpga if it is outputting pixel clock , lsync and fsync. These signals are the most important if any of the pixel(data) lines are not correct then you will get a bad image but if any one of the Clock, Fsync or Lsync are not found you will get no image. This if any of these signals are not there then it may mean a bad solder joint. You can debug by debug signal from FPGA>2. Check if FPGA outputs the same number of pixels on every frame. You would either need a Physical counter instrument  or a counter implemented in an FPGA. You need to count the exact number of pixels in a Frame. If FPGA output inconsistent number of byte every frame most UVC viewer will ignore frames, These may meen no image at all or massive drop in frame depending on how inconsistent your bytes are.
Checking FX31. FX3 part can be debugged by driving GPIO from GPIF or even C code. Debug frame sync Line sync etc. 2. To check if you are receiving any data at all from the camera. Then use wireshark with USBPcap to capture USB packets. You can easily find these packets and also count how many bytes FPGA is sending. 3. All the source files including sensor driver are present in repo. Only the sensor selected is included in the build. EZ USB suite allows you to select and deselect source files. EZ USB is eclipse based, Search on internet how to enable disable source in eclipse.4. If you are having a hard time resetting senor then it can be either permanently held out of reset with pull up or you can check how and which pins FPGA drive for resetting.
Sorry I do not have time for individual image builds. 
Regards

INDNextHenry, 2023-08-14:
@circuitvalley  Thanks for the reply, that' helps. I will read every word carefully.

Closed 2023-09-06.

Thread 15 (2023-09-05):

Files for debayer simulation

MohamedWHassan, 2023-09-05:
Hello,
can you upload the files used in the debayer testbench such as
italy.bmp768x512.raw
italy.bmp768x512.raw.rgb
italy.bmp768x512.raw.yuv
italy.bmp768x512.raw.verify

circuitvalley, 2023-09-06:
Raw file is added rest of the files are auto generated during simulation.
Commit. c76b455dc6708e8dc4d719f1ef93ee0b13e4a787

MohamedWHassan, 2023-10-17:
Hi,

Is it possible to tell me how did you manage to obtain the .RAW file?
I'm trying to find different RAW files with different bayer pattern but no luck so far.

Thanks

nokiagx, 2023-10-18:
Sorry, I don't know

At 2023-10-17 14:52:07, "MohamedWHassan" ***@***.***> wrote:

Hi,

Is it possible to tell me how did you manage to obtain the .RAW file?
I'm trying to find different RAW files with different bayer pattern but no luck so far.

Thanks

—
Reply to this email directly, view it on GitHub, or unsubscribe.
You are receiving this because you are subscribed to this thread.Message ID: ***@***.***>

kimstik, 2023-10-18:
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

https://swisscows.com/en/web?query=bayer+raw+image+sample
shows a lot of them:
https://stackoverflow.com/questions/27402422/where-can-i-download-raw-bayer-images
https://cs.brown.edu/courses/csci1290/labs/lab_raw/index.html

MohamedWHassan, 2023-10-18:
@kimstik
Thank you for the reply. But it is hard to find these RAW bayer images that could be used in the testbench as I've been looking for days.

I found this [repo](https://github.com/zhengtianyu1996/bayer_image_process) which has a img2raw matlab script and with some modifications it worked nicely.

nokiagx, 2023-10-18:
kimstik：

I remember not posting any comments or suggestions in this field.
我记得我没有发表过这个领域的评论或建议。

At 2023-10-18 16:51:22, "MohamedWHassan" ***@***.***> wrote:

@kimstik
Thank you for the reply. But it is hard to find these RAW bayer images that could be used in the testbench as I've been looking for days.

I found this repo which has a img2raw matlab script and with some modifications it worked nicely.

—
Reply to this email directly, view it on GitHub, or unsubscribe.
You are receiving this because you commented.Message ID: ***@***.***>

Closed 2023-09-06.

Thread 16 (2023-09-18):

Unable to find the instance/port 'mipi_data_p_in1[1]' in the constraint 'ldc_set_location -site {C1} [get_ports {mipi_data_p_in1[1]}]'

INDNextHenry, 2023-09-18:
Hi @circuitvalley

Full fpga build log.
[fpga-build-log.txt](https://github.com/circuitvalley/USB_C_Industrial_Camera_FPGA_USB3/files/12657952/fpga-build-log.txt)

I still try to repuduected this project, I encountered no signal output from some key pins(like Frame-sync, Line-Sync).
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

I found some clues when checking the compilation information. Does this mean that some signals of mipi are not configured correctly?
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

I am using the default pdc file, please give me some suggestions, thank you.

circuitvalley, 2023-10-21:
Comment from code. If you do not have ES chip then you can remove second MIPI port from top level.

//Lattice FPGA Engineering sample chip does not allow manual PHY pin assignment* for PHY and our hardware uses PHY1 rather than PHY0, this instance with go to PHY0 while our actual instance will go to PHY 1
//*Lattice Does allow manual pin assignment but when you assign manually PHY will not work at all. Appears to be ES chip bug.
//As i am using Lattice ES chips i need to use Radiant 2.0 , DPHY IP has been changed a little with Radiant 3.1
// If using ES Devices a dummy dphy_ip need to inferred as a place holder

Closed 2023-10-21.

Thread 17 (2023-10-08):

FX3 logs print "DMA Reset Event: Frame timer overflow, time period = 400"

INDNextHenry, 2023-10-08:
1. After some modify, the netlist analyzer is like this:
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

2. After programn the FPGA bitstream file, webcamoid has nothing, and FX3 log as here, says frame timeout:
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

Not sure is which part has the issue.

circuitvalley, 2023-10-21:
This indicates there is no packets from FPGA to USB controller,

There are few tips I could give you. How to debug if things are not working for you.Checking FPGA

Check fpga if it is outputting pixel clock , lsync and fsync. These signals are the most important if any of the pixel(data) lines are not correct then you will get a bad image but if any one of the Clock, Fsync or Lsync are not found you will get no image. This if any of these signals are not there then it may mean a bad solder joint. You can debug by debug signal from FPGA.
Check if FPGA outputs the same number of pixels on every frame. You would either need a Physical counter instrument  or a counter implemented in an FPGA. You need to count the exact number of pixels in a Frame. If FPGA output inconsistent number of byte every frame most UVC viewer will ignore frames, These may meen no image at all or massive drop in frame depending on how inconsistent your bytes are.
Checking FX3

FX3 part can be debugged by driving GPIO from GPIF or even C code. Debug frame sync Line sync etc.

To check if you are receiving any data at all from the camera. Then use wireshark with USBPcap to capture USB packets. You can easily find these packets and also count how many bytes FPGA is sending.

All the source files including sensor driver are present in repo. Only the sensor selected is included in the build. EZ USB suite allows you to select and deselect source files. EZ USB is eclipse based, Search on internet how to enable disable source in eclipse.4. If you are having a hard time resetting senor then it can be either permanently held out of reset with pull up or you can check how and which pins FPGA drive for resetting.
Sorry I do not have time for individual image builds.
Regards

Closed 2023-10-22.

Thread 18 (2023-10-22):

Anyone with extra hardware?

nategreco, 2023-10-22:
I'd like to use this project as a development/learning platform but I don't think it's practical for me to get a single piece of each board manufactured for myself - Does anyone have any extra hardware that they'd be willing to sell to someone in the US?

Thanks

INDNextHenry, 2023-10-23:
I have some, but it really hard to new fish to recopy this project. Beause it lacks bins && fw to verify the board.

nategreco, 2023-10-23:
Ugh, that's a good point. So you had boards made but have yet to verify they work?

INDNextHenry, 2023-10-23:
Already fight for months, little process made. I'm zero level on lattice fpga, not for reference, hahah.

nategreco, 2023-10-23:
I'm in a similar boat. I know a little verilog but it does seem daunting to spin up a lattice project from scratch.

Well if you had extras of all three boards and had any confidence they worked I'd be excited to buy them off you. I haven't looked into getting them fabricated myself but I figure both JLPCB and PCBway have minimum order quantities for assembled boards.

nategreco, 2023-10-23:
I'm in a similar boat. I know a little verilog but it does seem daunting to spin up a lattice project from scratch.

Well if you had extras of all three boards and had any confidence they worked I'd be excited to buy them off you. I haven't looked into getting them fabricated myself but I figure both JLPCB and PCBway have minimum order quantities for assembled boards.

INDNextHenry, 2023-10-25:
> I'm in a similar boat. I know a little verilog but it does seem daunting to spin up a lattice project from scratch.
>
> Well if you had extras of all three boards and had any confidence they worked I'd be excited to buy them off you. I haven't looked into getting them fabricated myself but I figure both JLPCB and PCBway have minimum order quantities for assembled boards.

I am happy to share my boards. I'm in China, where are your location?

nategreco, 2023-10-25:
US - Shipping will probably be expensive but if you're willing to ship it I'd cover the cost.

mca312, 2023-11-06:
Nate, did you the parts? I'm about to order some once I find the dimensions for the IMX273.

nategreco, 2023-11-06:
No, I haven't ordered anything yet. Are you buying yours turnkey assembled?

mca312, 2023-11-07:
I was going to order the image and FPGA board and place the parts myself.  But I'm looking at an IMX273 (or 252) and need to get the footprints for it first.  Also looks like there may be an issue in the design from the other open issue.

circuitvalley, 2023-12-02:
There will a second revision of this camera under development.

Closed 2023-12-02.

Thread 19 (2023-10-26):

The connector pins between FX3 and FPGA boards are mismatch

INDNextHenry, 2023-10-26:
Hi @circuitvalley

I found that there are 3 pairs of pins on the upper connector of the FPGA and the lower connector of the USB3-FX3 that do not match, and the remaining 50 or so pins match normally. Is this a mistake or is it intentional design?

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

mca312, 2023-11-05:
Any luck on this? I’m about to start on a prototype

INDNextHenry, 2023-11-07:
> Any luck on this? I’m about to start on a prototype

No one mentioned this point, and very few people put this project into practical action.

circuitvalley, 2023-12-02:
Only names are in correct, This is fixed in constrain files pin assignment,

Closed 2023-12-02.

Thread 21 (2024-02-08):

Where to buy assembled

tizbac, 2024-02-08:
Is there any way / place to buy electronic part of the project assembled?

circuitvalley, 2025-07-27:
Newer version of camera is ready That would be available for purchase

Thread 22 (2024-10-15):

What other sensors does it support?

maifeeulasad, 2024-10-15:
As per documentation we only have support for `IMX477`, `IMX219`, `IMX290`, `IMX327`, `IMX462` these sensors. What other sensors does it support?

circuitvalley, 2024-10-15:
Any Sensor from which Support RAW10 to RAW14 Will work as is as long as its MIPI and you have I2C driver for initializing.

maifeeulasad, 2024-10-15:
Thanks for the details really appreciate it.

Closed 2024-10-15.

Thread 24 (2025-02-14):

Error

y-runwal, 2025-02-14:
ERROR <35901010> - c:/users/admin/documents/radiant projects/mipi_csi/source/impl_1/mipi_csi_16_nx.v(161): cannot find port hs_rx_clk_en_i on this module. VERI-1010
got this error while synthesizing.

following is my tree

│   .recovery
│   mipi_csi.rdf
│   mipi_csi1.sty
│   mipi_csi_tcl.html
│   promote.pfl
│   promote.xml
│   tree.txt
│
├───csi
│   │   component.xml
│   │   csi.cfg
│   │   csi.ipx
│   │   design.xml
│   │
│   ├───constraints
│   │       constraint.sdc
│   │       csi.ldc
│   │
│   ├───eval
│   │   │   constraint_eval.pdc
│   │   │   dut_inst.v
│   │   │   dut_params.v
│   │   │   eval_top.sv
│   │   │   eval_top_inst.v
│   │   │
│   │   ├───source
│   │   │       defines_avant.v
│   │   │       defines_cpnx.v
│   │   │       defines_tb.v
│   │   │       lscc_byte_check.sv
│   │   │       lscc_byte_ctrlr.sv
│   │   │       lscc_byte_gen.sv
│   │   │       lscc_data_checker.sv
│   │   │       lscc_lmmi_psctrl.sv
│   │   │       lscc_mipi_rx.sv
│   │   │       lscc_mipi_tx.sv
│   │   │       lscc_mipi_val_top.sv
│   │   │       lscc_rst_sync.sv
│   │   │       lscc_stim_gen.sv
│   │   │       tb_top.sv
│   │   │
│   │   └───sw
│   │       │   dphy_loopback_ed.rdf
│   │       │   dphy_loopback_ed1.sty
│   │       │   post_syn_sys_avant.pdc
│   │       │   post_syn_sys_cpnx.pdc
│   │       │
│   │       ├───dphyrx_ip
│   │       │   │   component.xml
│   │       │   │   design.xml
│   │       │   │   dphyrx_ip.cfg
│   │       │   │   dphyrx_ip.ipx
│   │       │   │
│   │       │   ├───constraints
│   │       │   │       constraint.sdc
│   │       │   │       dphyrx_ip.ldc
│   │       │   │
│   │       │   ├───eval
│   │       │   │       constraint_eval.pdc
│   │       │   │       dut_inst.v
│   │       │   │       dut_params.v
│   │       │   │       eval_top.sv
│   │       │   │       eval_top_inst.v
│   │       │   │
│   │       │   └───rtl
│   │       │           dphyrx_ip.sv
│   │       │           dphyrx_ip_bb.v
│   │       │
│   │       ├───dphytx_ip
│   │       │   │   component.xml
│   │       │   │   design.xml
│   │       │   │   dphytx_ip.cfg
│   │       │   │   dphytx_ip.ipx
│   │       │   │
│   │       │   ├───constraints
│   │       │   │       constraint.sdc
│   │       │   │       dphytx_ip.ldc
│   │       │   │
│   │       │   ├───eval
│   │       │   │       constraint_eval.pdc
│   │       │   │       dut_inst.v
│   │       │   │       dut_params.v
│   │       │   │       eval_top.sv
│   │       │   │       eval_top_inst.v
│   │       │   │
│   │       │   └───rtl
│   │       │           dphytx_ip.sv
│   │       │           dphytx_ip_bb.v
│   │       │
│   │       └───pll_0_ip
│   │           │   component.xml
│   │           │   design.xml
│   │           │   ip_gen_cfg_file.cfg
│   │           │   pll_0_ip.cfg
│   │           │   pll_0_ip.ipx
│   │           │
│   │           ├───constraints
│   │           │       constraint.sdc
│   │           │       pll_0_ip.ldc
│   │           │
│   │           └───rtl
│   │                   pll_0_ip.v
│   │                   pll_0_ip_bb.v
│   │
│   ├───misc
│   │       csi_tmpl.v
│   │       csi_tmpl.vhd
│   │
│   ├───rtl
│   │       csi.sv
│   │       csi_bb.v
│   │
│   └───testbench
│           dut_inst.v
│           dut_params.v
│           lscc_dphy_tx_model.sv
│           rx_model.sv
│           tb_top.sv
│
├───impl_1
│       .build_status
│       .synthesis_touch
│       ._Real_._Math_.vhd
│       automake.log
│       hdla_gen_hierarchy.html
│       hdr_log
│       ipsdclist.txt
│       message_log.xml
│       mipi_csi_impl_1.arearep
│       mipi_csi_impl_1_ip_summary.xml
│       mipi_csi_impl_1_lattice.srp
│       mipi_csi_impl_1_lattice.synproj
│       mipi_csi_impl_1_lattice_lse.html
│       mipi_csi_impl_1_lseres.html
│       mipi_csi_impl_1_rtl.lsedata
│       mipi_csi_impl_1_rtl.udb
│       mipi_csi_impl_1_summary.html
│       mipi_csi_impl_1_syn.psn
│       mipi_csi_impl_1_syn.udb
│       mipi_csi_impl_1_synpsn.html
│       mipi_csi_impl_1_synthesize.tcl
│
├───ok
│   │   component.xml
│   │   design.xml
│   │   ok.cfg
│   │   ok.ipx
│   │
│   ├───constraints
│   │       constraint.sdc
│   │       ok.ldc
│   │
│   ├───eval
│   │   │   constraint_eval.pdc
│   │   │   dut_inst.v
│   │   │   dut_params.v
│   │   │   eval_top.sv
│   │   │   eval_top_inst.v
│   │   │
│   │   ├───source
│   │   │       defines_avant.v
│   │   │       defines_cpnx.v
│   │   │       defines_tb.v
│   │   │       lscc_byte_check.sv
│   │   │       lscc_byte_ctrlr.sv
│   │   │       lscc_byte_gen.sv
│   │   │       lscc_data_checker.sv
│   │   │       lscc_lmmi_psctrl.sv
│   │   │       lscc_mipi_rx.sv
│   │   │       lscc_mipi_tx.sv
│   │   │       lscc_mipi_val_top.sv
│   │   │       lscc_rst_sync.sv
│   │   │       lscc_stim_gen.sv
│   │   │       tb_top.sv
│   │   │
│   │   └───sw
│   │       │   dphy_loopback_ed.rdf
│   │       │   dphy_loopback_ed1.sty
│   │       │   post_syn_sys_avant.pdc
│   │       │   post_syn_sys_cpnx.pdc
│   │       │
│   │       ├───dphyrx_ip
│   │       │   │   component.xml
│   │       │   │   design.xml
│   │       │   │   dphyrx_ip.cfg
│   │       │   │   dphyrx_ip.ipx
│   │       │   │
│   │       │   ├───constraints
│   │       │   │       constraint.sdc
│   │       │   │       dphyrx_ip.ldc
│   │       │   │
│   │       │   ├───eval
│   │       │   │       constraint_eval.pdc
│   │       │   │       dut_inst.v
│   │       │   │       dut_params.v
│   │       │   │       eval_top.sv
│   │       │   │       eval_top_inst.v
│   │       │   │
│   │       │   └───rtl
│   │       │           dphyrx_ip.sv
│   │       │           dphyrx_ip_bb.v
│   │       │
│   │       ├───dphytx_ip
│   │       │   │   component.xml
│   │       │   │   design.xml
│   │       │   │   dphytx_ip.cfg
│   │       │   │   dphytx_ip.ipx
│   │       │   │
│   │       │   ├───constraints
│   │       │   │       constraint.sdc
│   │       │   │       dphytx_ip.ldc
│   │       │   │
│   │       │   ├───eval
│   │       │   │       constraint_eval.pdc
│   │       │   │       dut_inst.v
│   │       │   │       dut_params.v
│   │       │   │       eval_top.sv
│   │       │   │       eval_top_inst.v
│   │       │   │
│   │       │   └───rtl
│   │       │           dphytx_ip.sv
│   │       │           dphytx_ip_bb.v
│   │       │
│   │       └───pll_0_ip
│   │           │   component.xml
│   │           │   design.xml
│   │           │   ip_gen_cfg_file.cfg
│   │           │   pll_0_ip.cfg
│   │           │   pll_0_ip.ipx
│   │           │
│   │           ├───constraints
│   │           │       constraint.sdc
│   │           │       pll_0_ip.ldc
│   │           │
│   │           └───rtl
│   │                   pll_0_ip.v
│   │                   pll_0_ip_bb.v
│   │
│   ├───misc
│   │       ok_tmpl.v
│   │       ok_tmpl.vhd
│   │
│   ├───rtl
│   │       ok.sv
│   │       ok_bb.v
│   │
│   └───testbench
│           bus_driver.sv
│           clk_driver.sv
│           csi2_model.sv
│           dsi_model.sv
│           dut_inst.v
│           dut_params.v
│           tb_top.sv
│
└───source
    └───impl_1
            camera_controller.v
            csi_16_nx.ldc
            csi_16_nx.pdc
            csi_dphy.cfg
            csi_dphy.v
            debayer_filter.v
            dphy_dummy.cfg
            dphy_dummy.v
            frame_detector.v
            int_osc.v
            line_ram_dp.cfg
            line_ram_dp.v
            lsync_reset_generator.v
            mipi_csi_16_nx.v
            mipi_csi_rx_byte_aligner.v
            mipi_csi_rx_lane_aligner.v
            mipi_csi_rx_packet_decoder_16b2lane.v
            mipi_csi_rx_packet_decoder_16b4lane.v
            mipi_csi_rx_packet_decoder_8b2lane.v
            mipi_csi_rx_packet_decoder_8b4lane.v
            mipi_csi_rx_raw_depacker_16b2lane.v
            mipi_csi_rx_raw_depacker_16b4lane.v
            mipi_csi_rx_raw_depacker_8b2lane.v
            mipi_csi_rx_raw_depacker_8b2lane_2ppc.v
            mipi_csi_rx_raw_depacker_8b4lane.v
            mipi_csi_rx_raw_depacker_8b4lane_8ppc.v
            output_reformatter.v
            out_line_ram_dp.cfg
            out_line_ram_dp.v
            rgb_to_yuv.v
            rom_first.cfg
            rom_first.mem
            rom_first.v
            rom_sec.cfg
            rom_sec.v
            rom_second.mem
            sample_generator.v

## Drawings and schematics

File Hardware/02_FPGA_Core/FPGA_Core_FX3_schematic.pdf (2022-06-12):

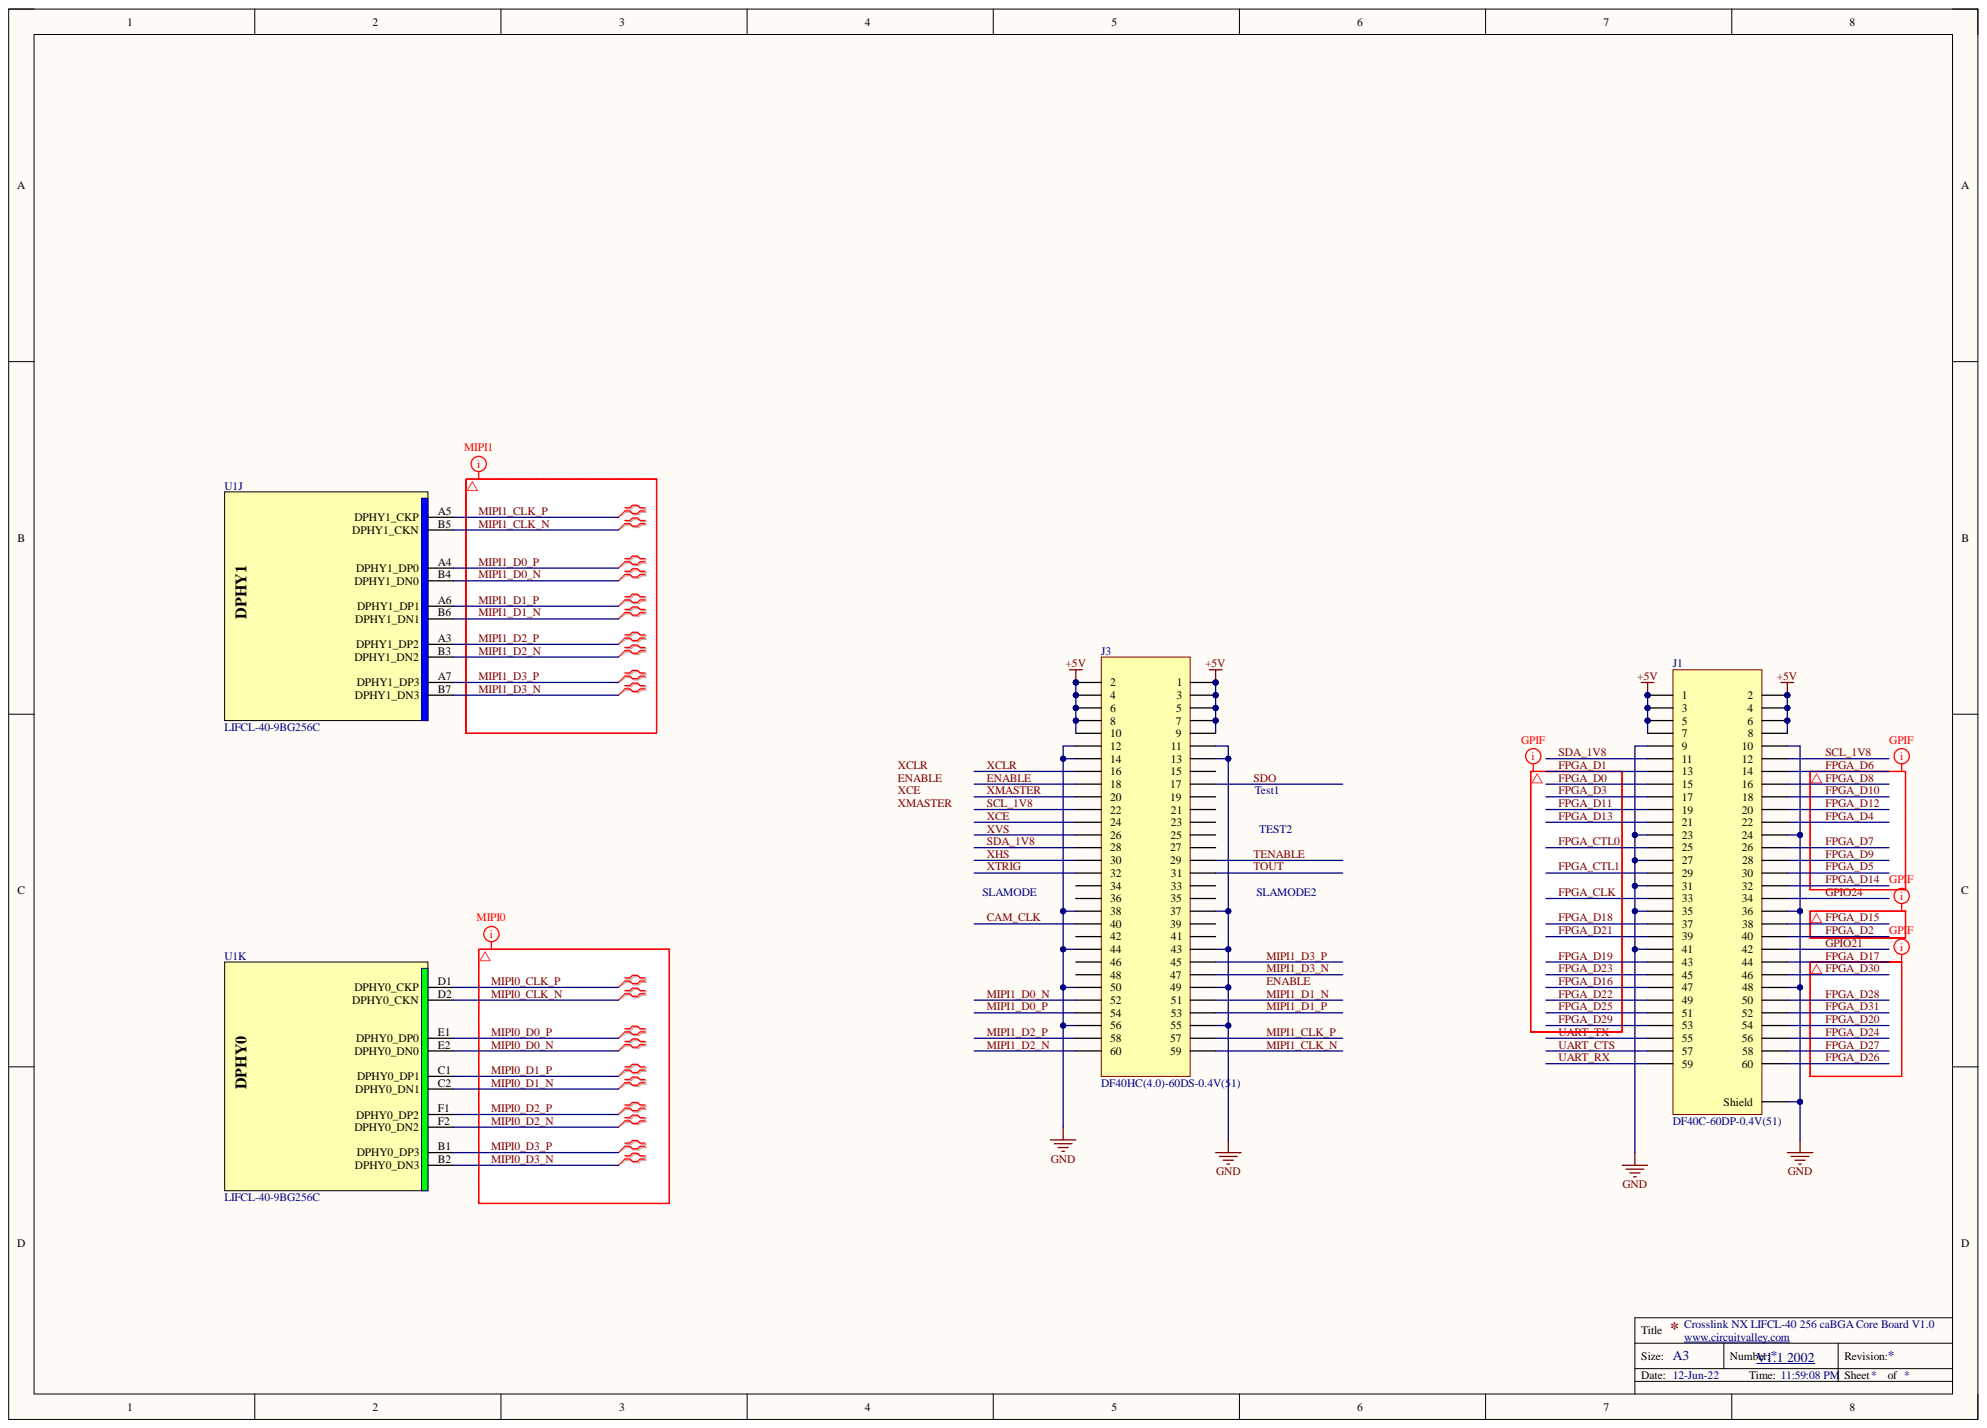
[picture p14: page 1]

Si ze: A | Number: V 1.1 2 | Rev isi on:

Date: 12-Jun-22 T i me: 11:59:08 PM | | Shee t * o f

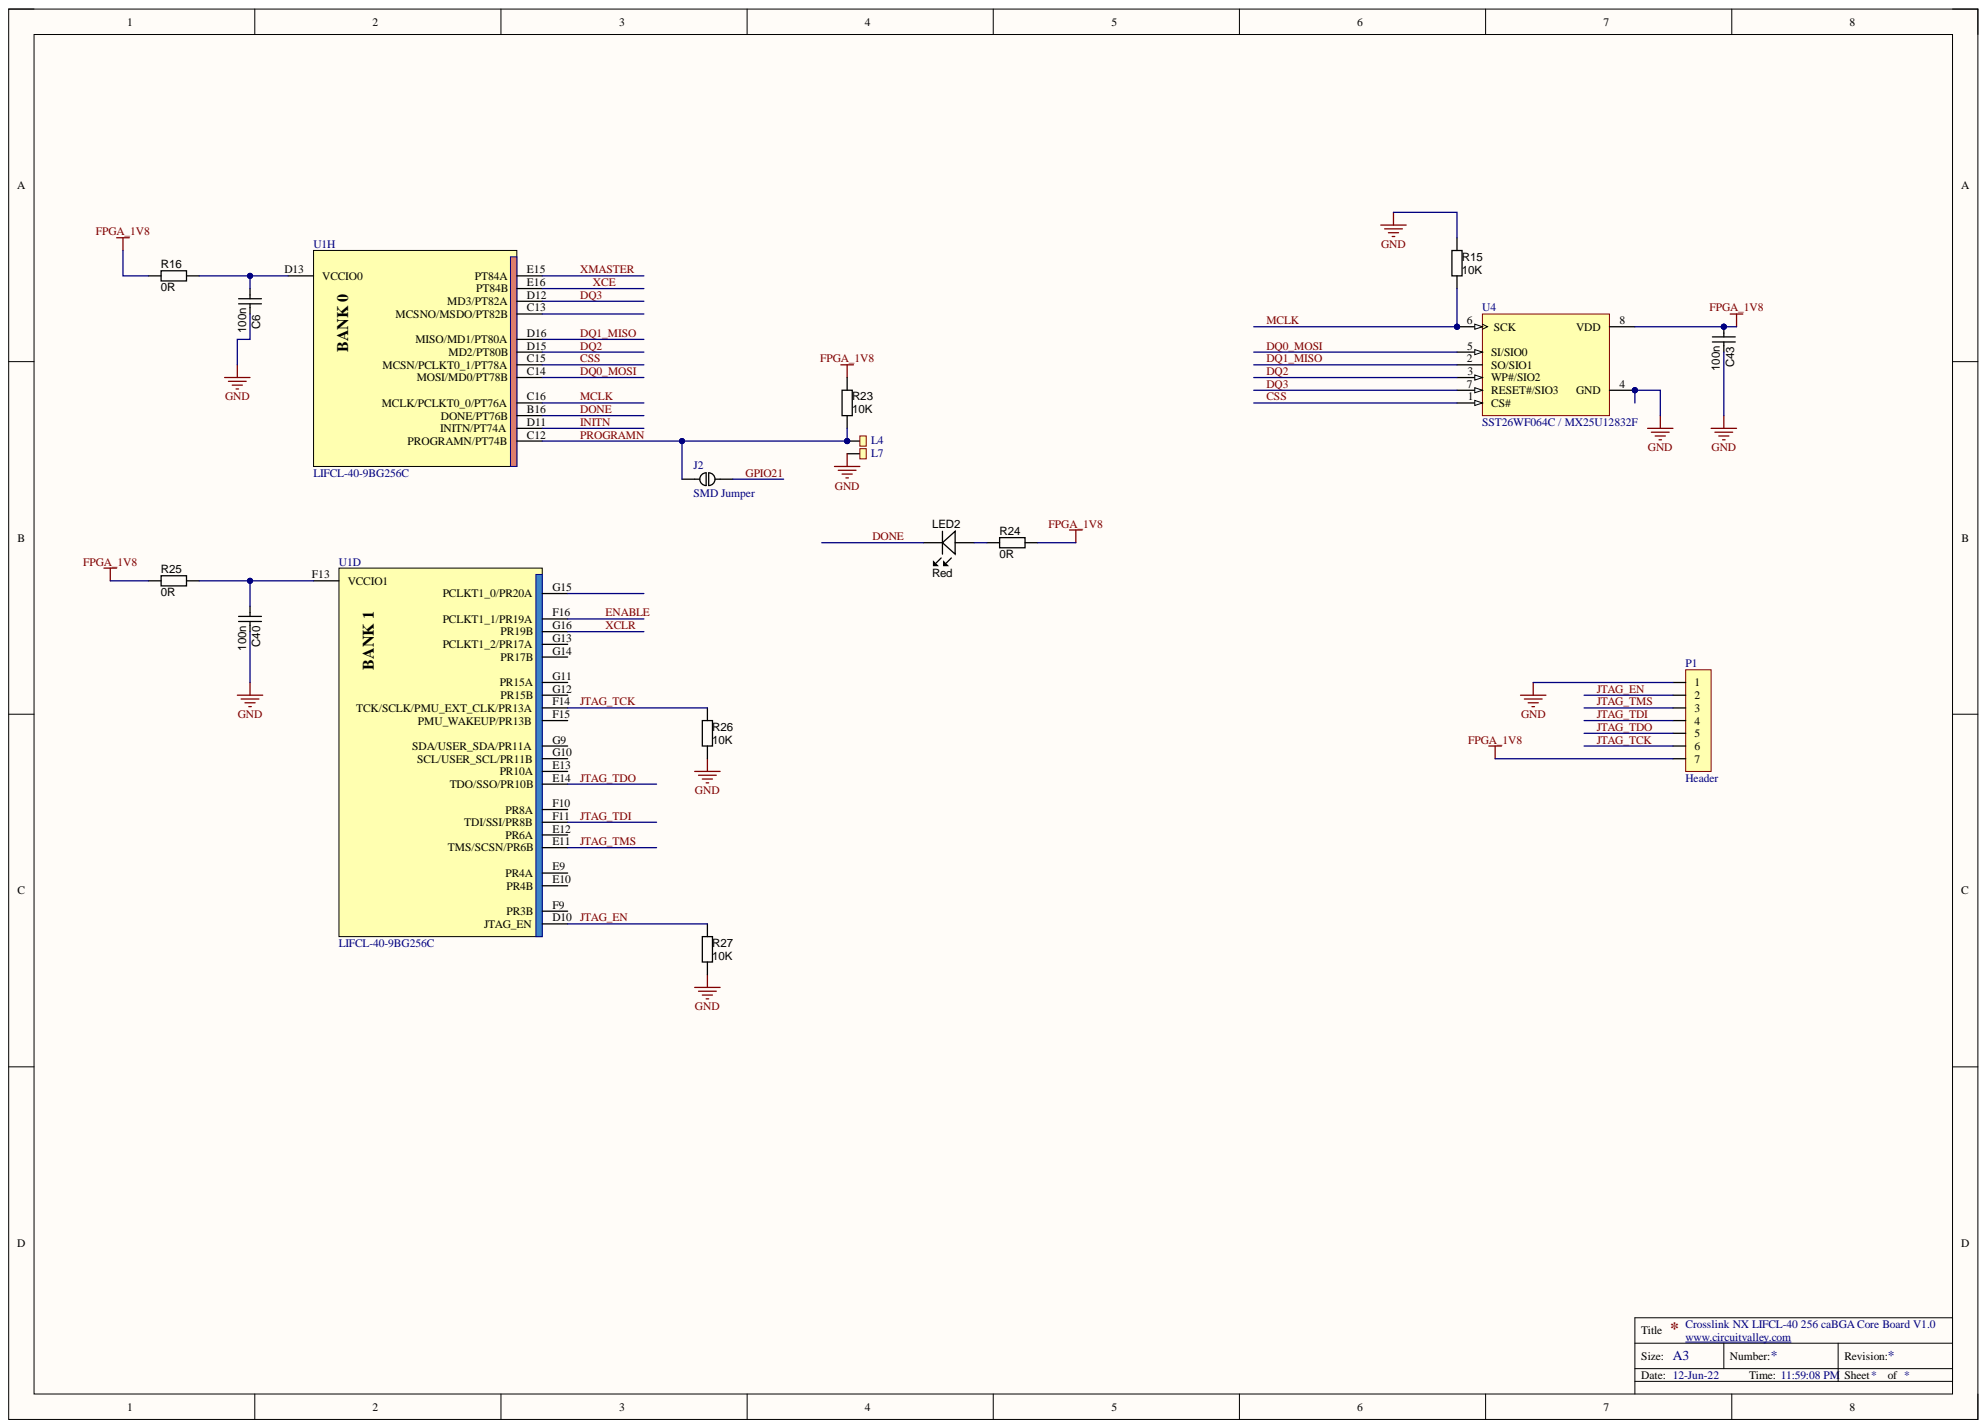
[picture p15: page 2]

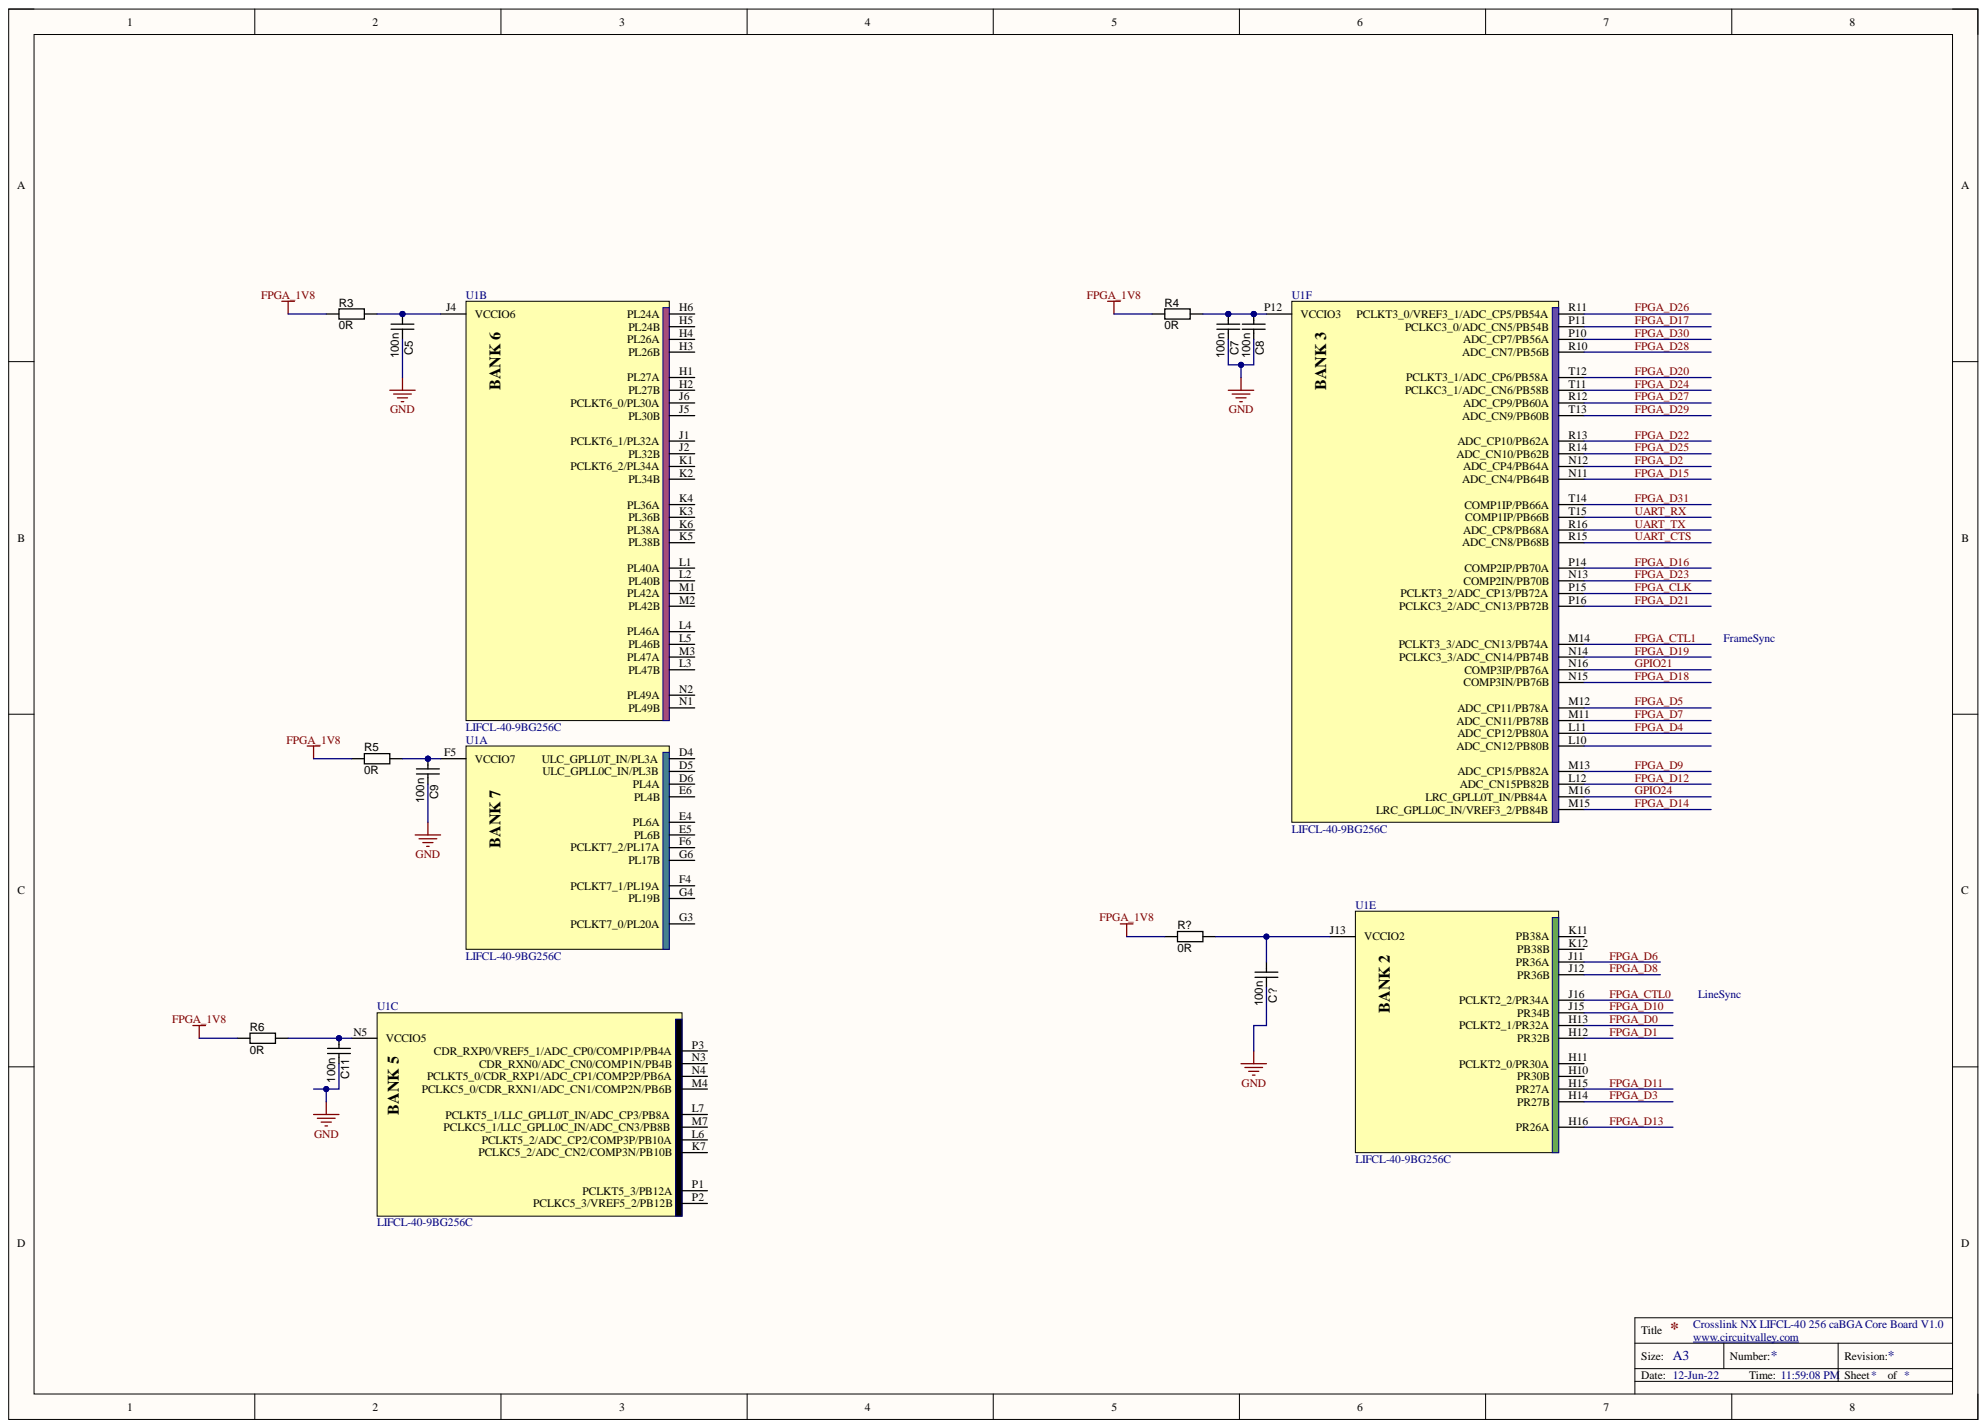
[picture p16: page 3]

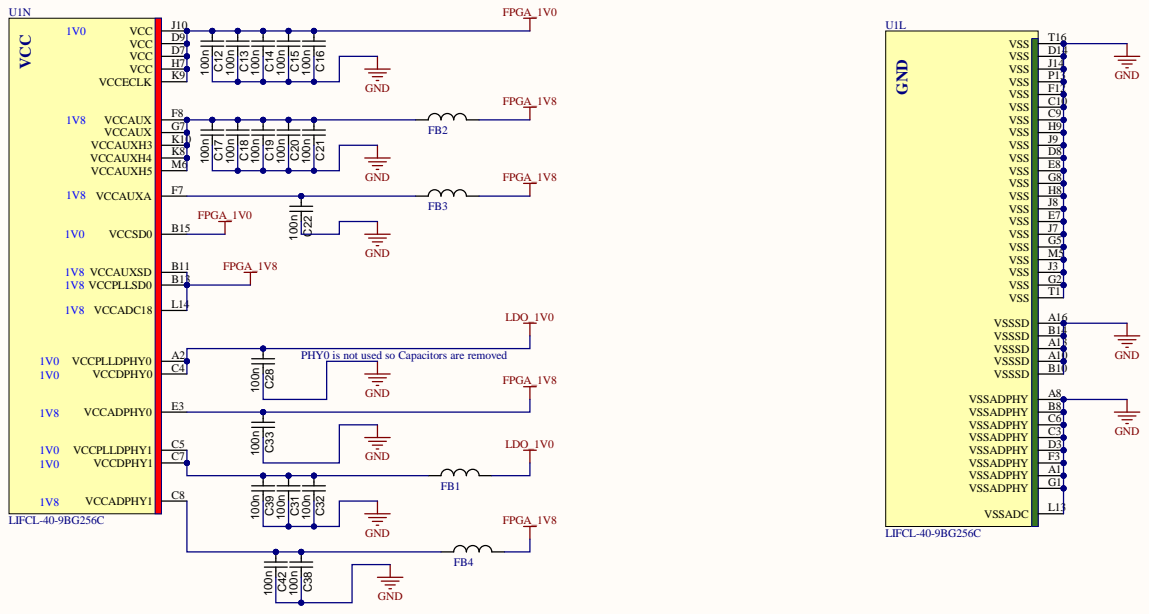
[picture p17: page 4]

PHY0 is not used so Capacitors are removed

Crosslink NX LIFCL-40 256 caBGA Core Board V1.0
Title

Size: A3 | Number: * | Revision: *

12-Jun-22 Time: 11:59:08 PM | | Sheet * of *

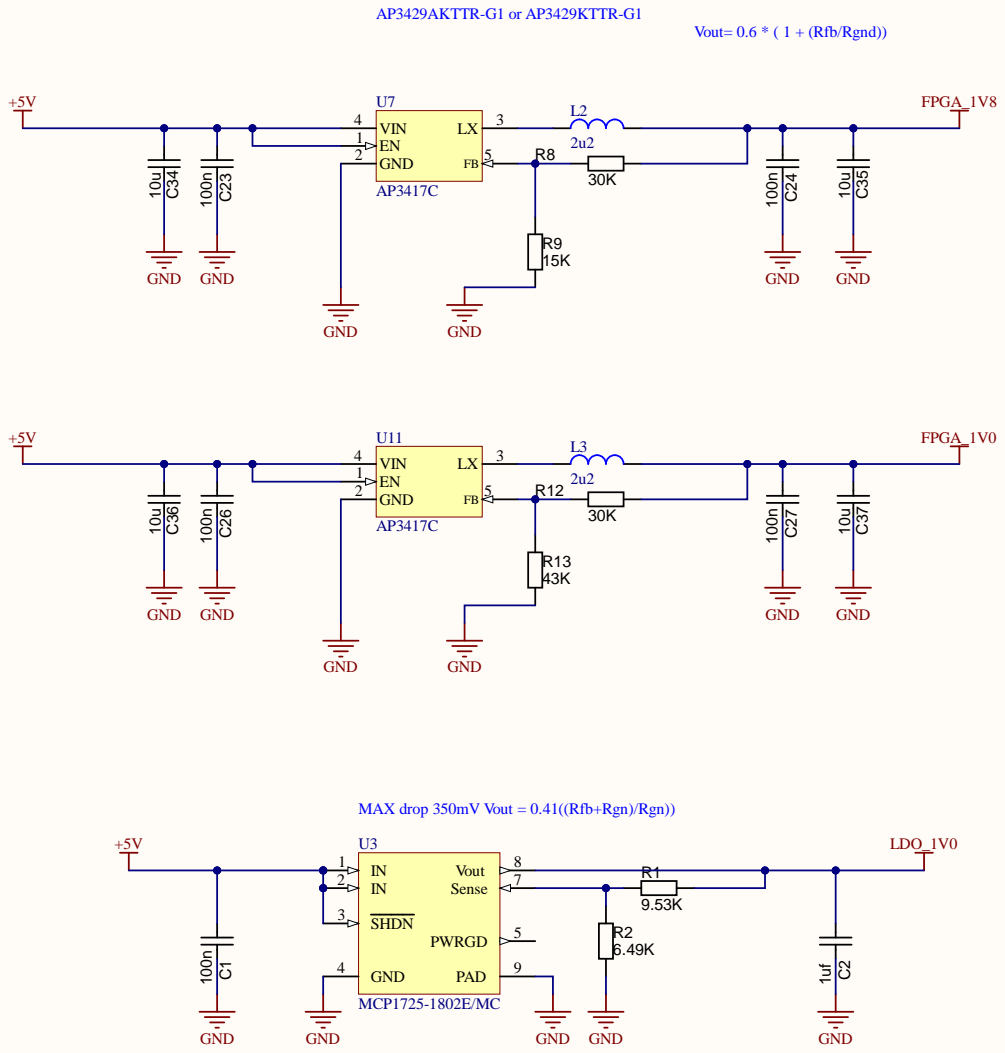
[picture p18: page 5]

MAX drop 350mV Vout = 0.41((Rfb+Rgn)/Rgn))

Crosslink NX LIFCL-40 256 caBGA Core Board V1.0
Title

Size: A3 | Number: * | Revision: *

12-Jun-22 Time: 11:59:08 PM | | Sheet * of *

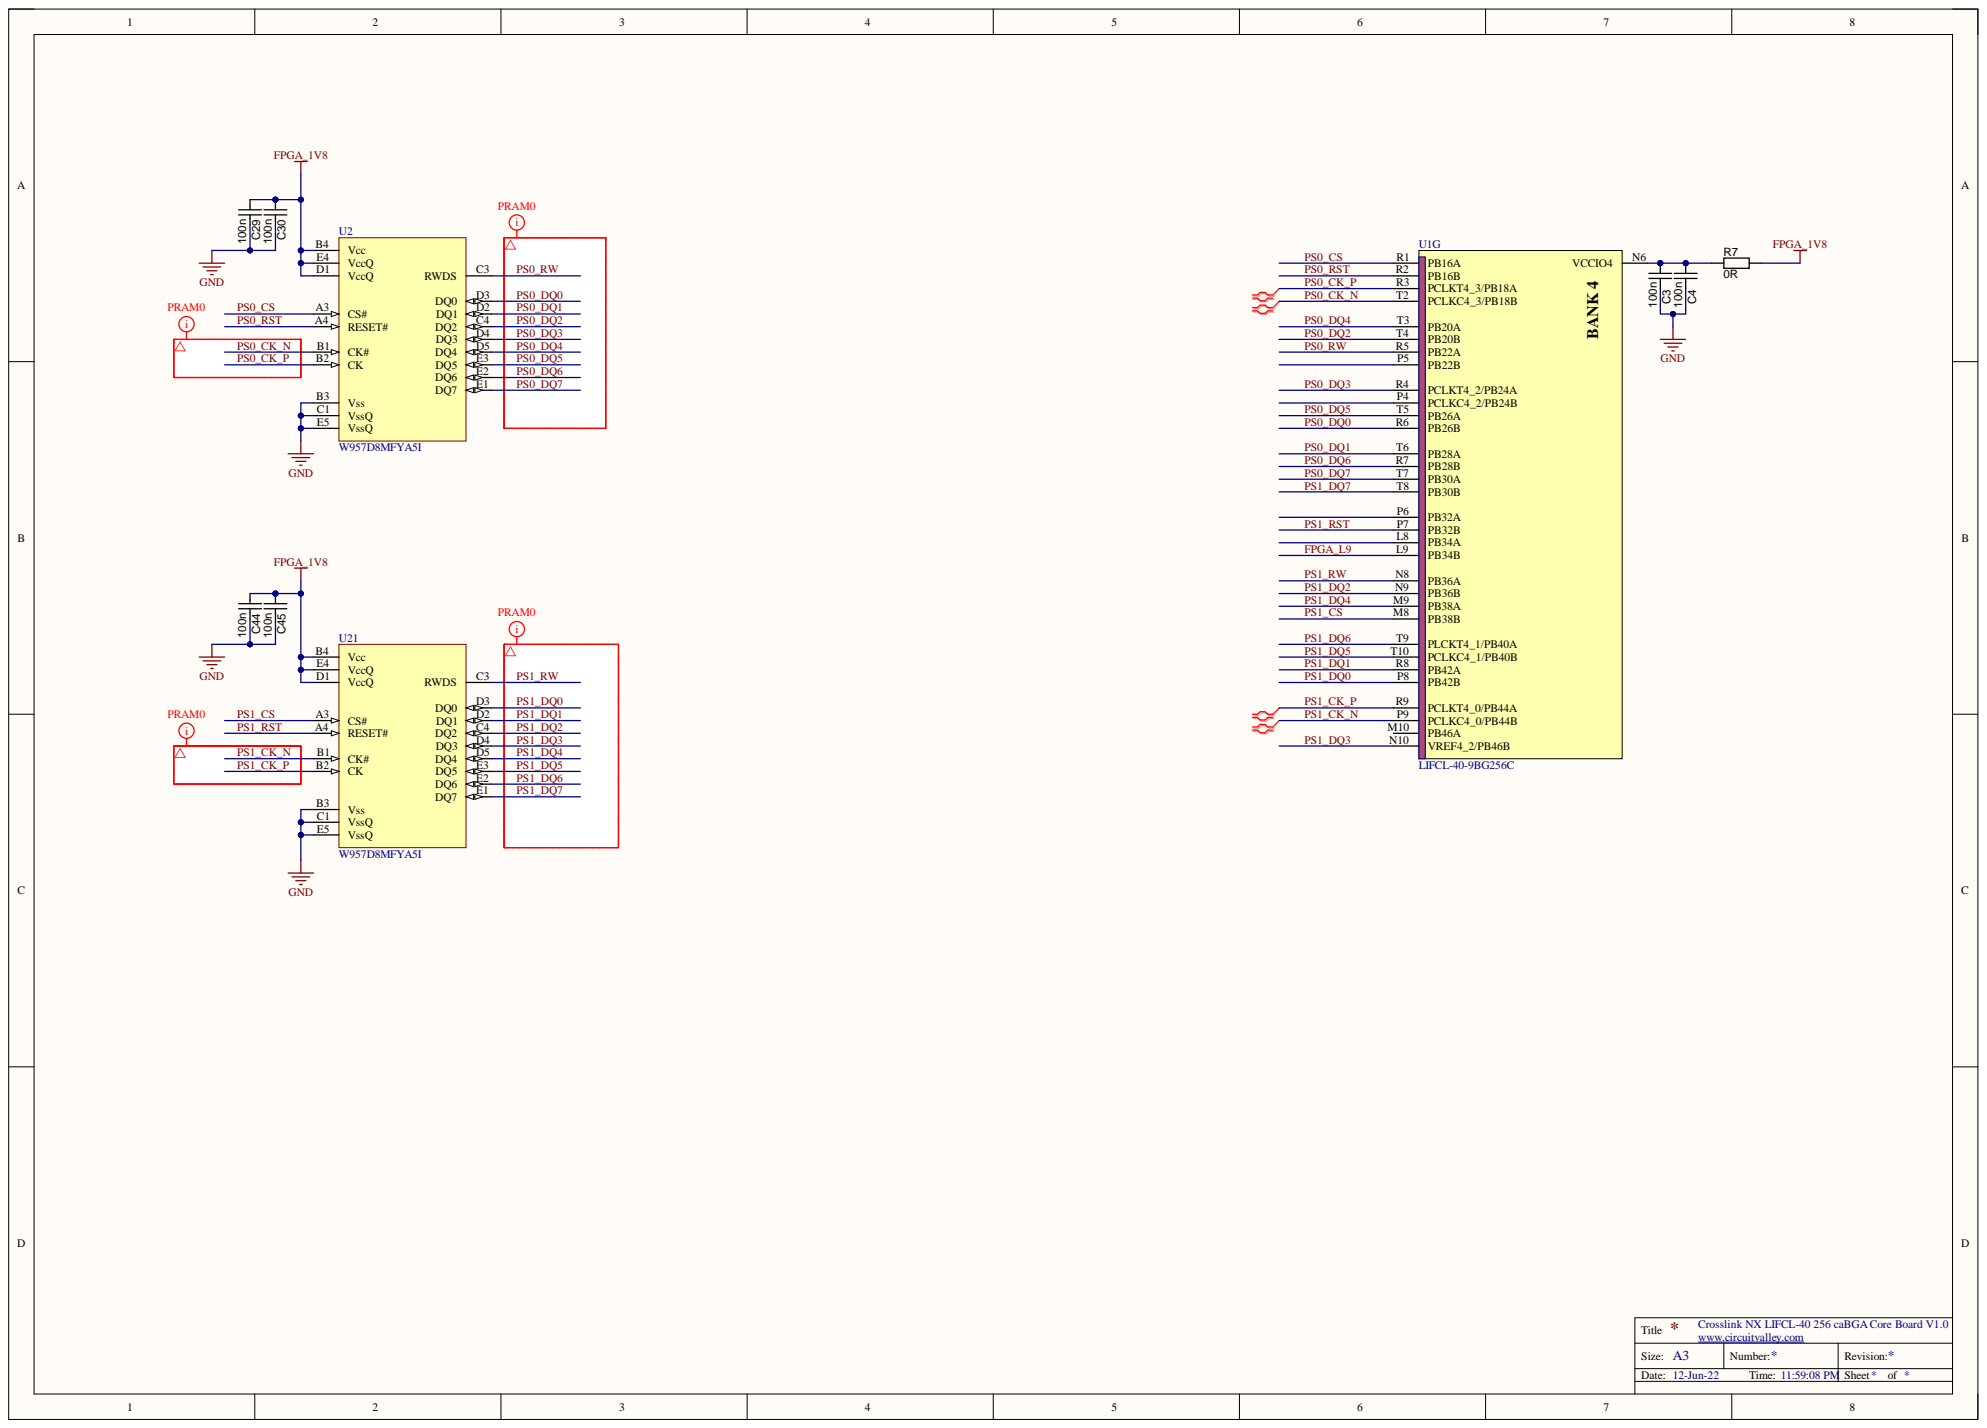
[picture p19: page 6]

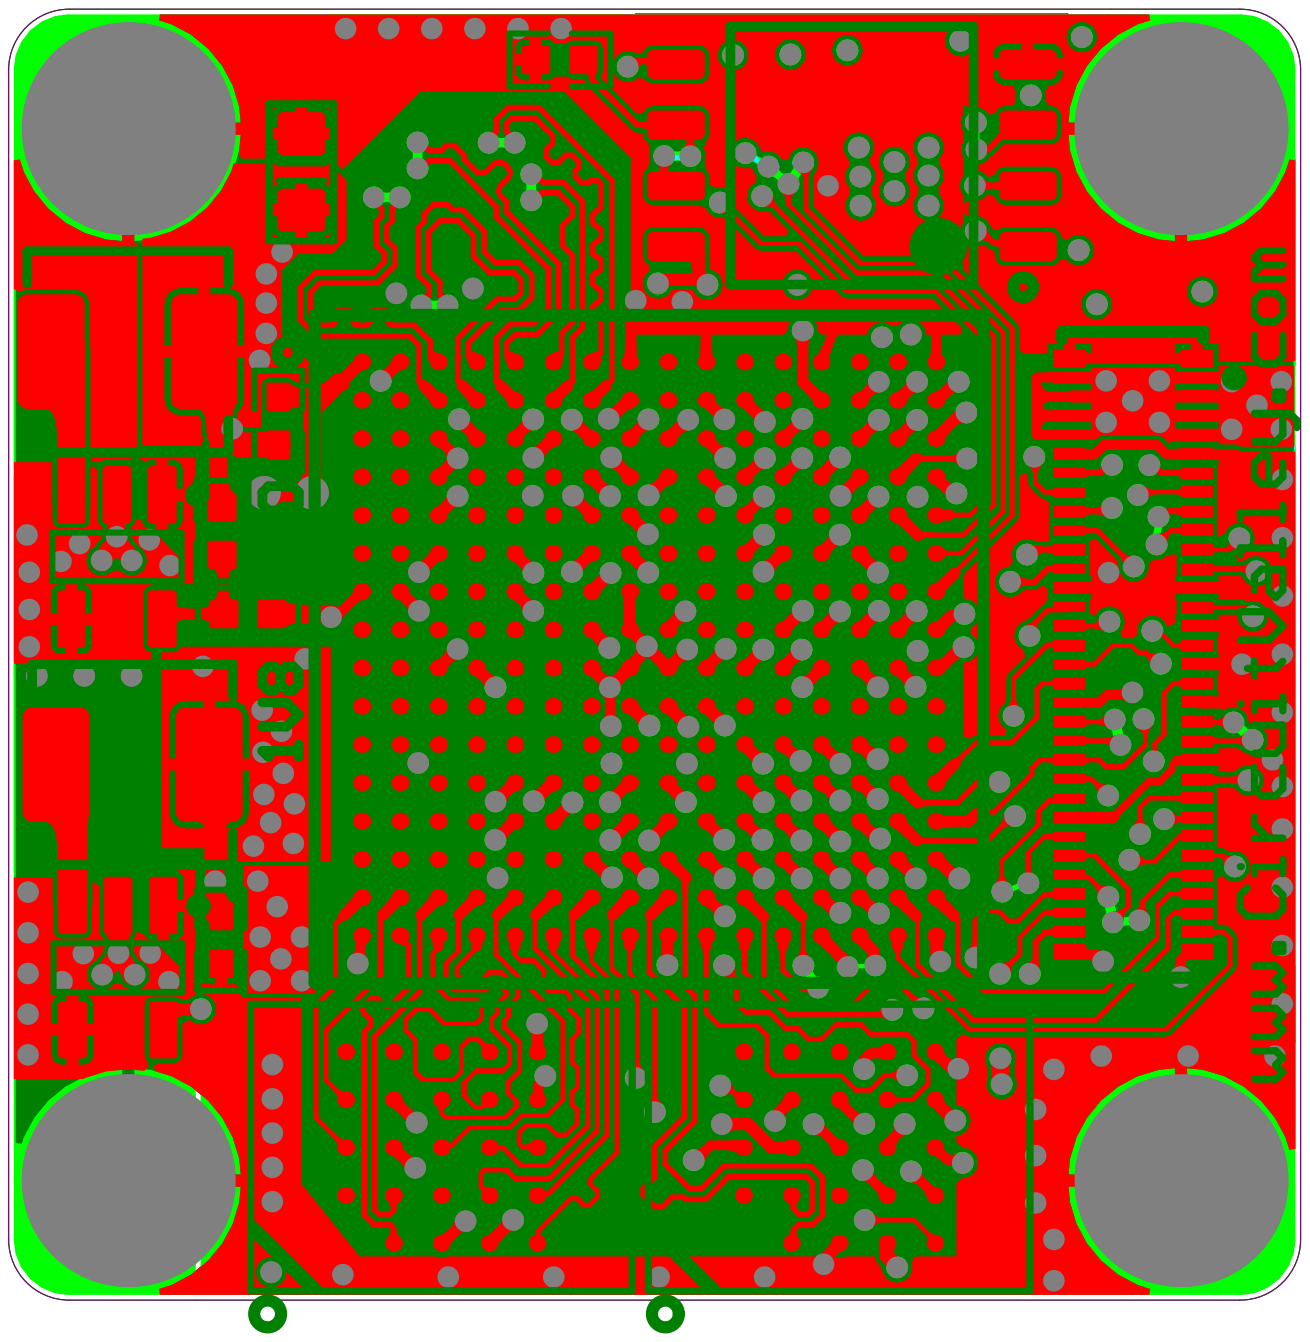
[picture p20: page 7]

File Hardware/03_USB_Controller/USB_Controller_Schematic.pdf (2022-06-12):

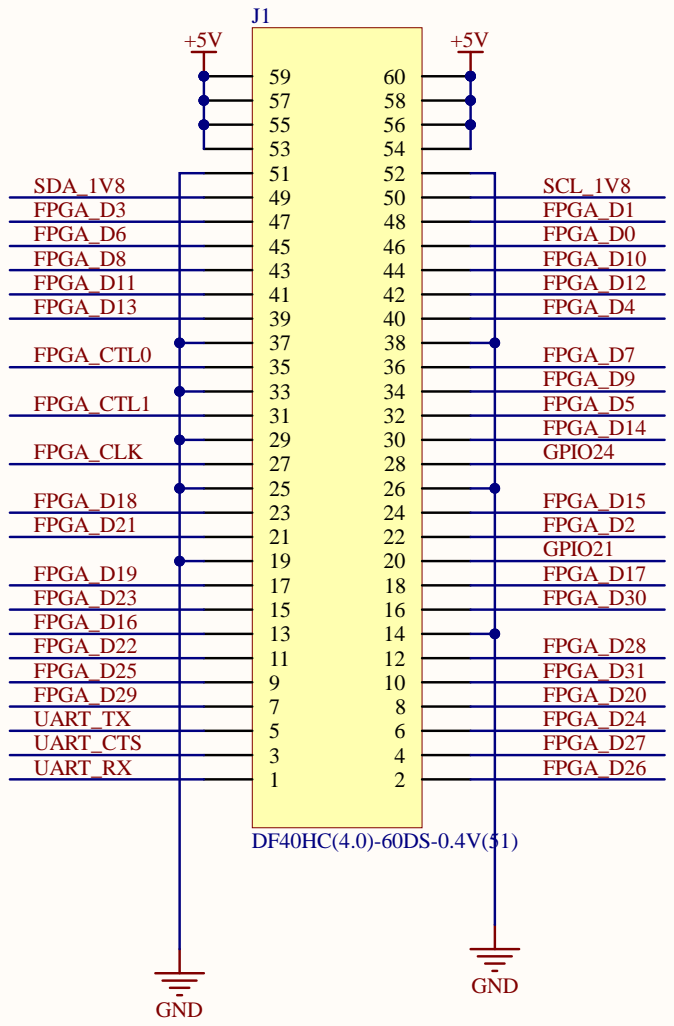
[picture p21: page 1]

Si ze: A | Number: * V 1.1 2 | Rev isi on: *

Date: 13-Jun-22 T i me: 12: 11:03 AM | | Shee t * o f *

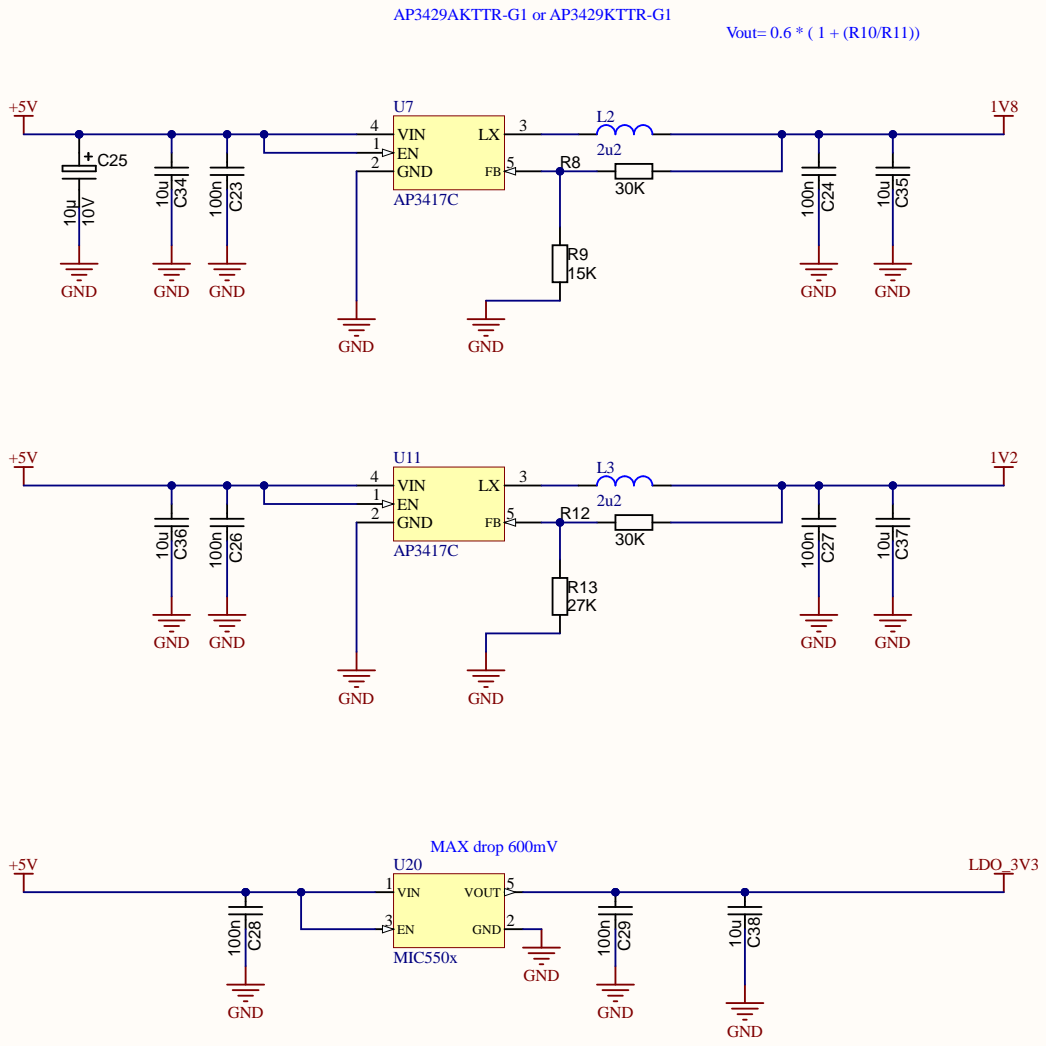
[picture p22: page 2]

Size: A3 | Number: * | Revision: *

13-Jun-22 Time: 12:11:03 AM | | Sheet * of *

C:\Users\gaurav\Documents\Altium\cam_FX3\power.SchDoc

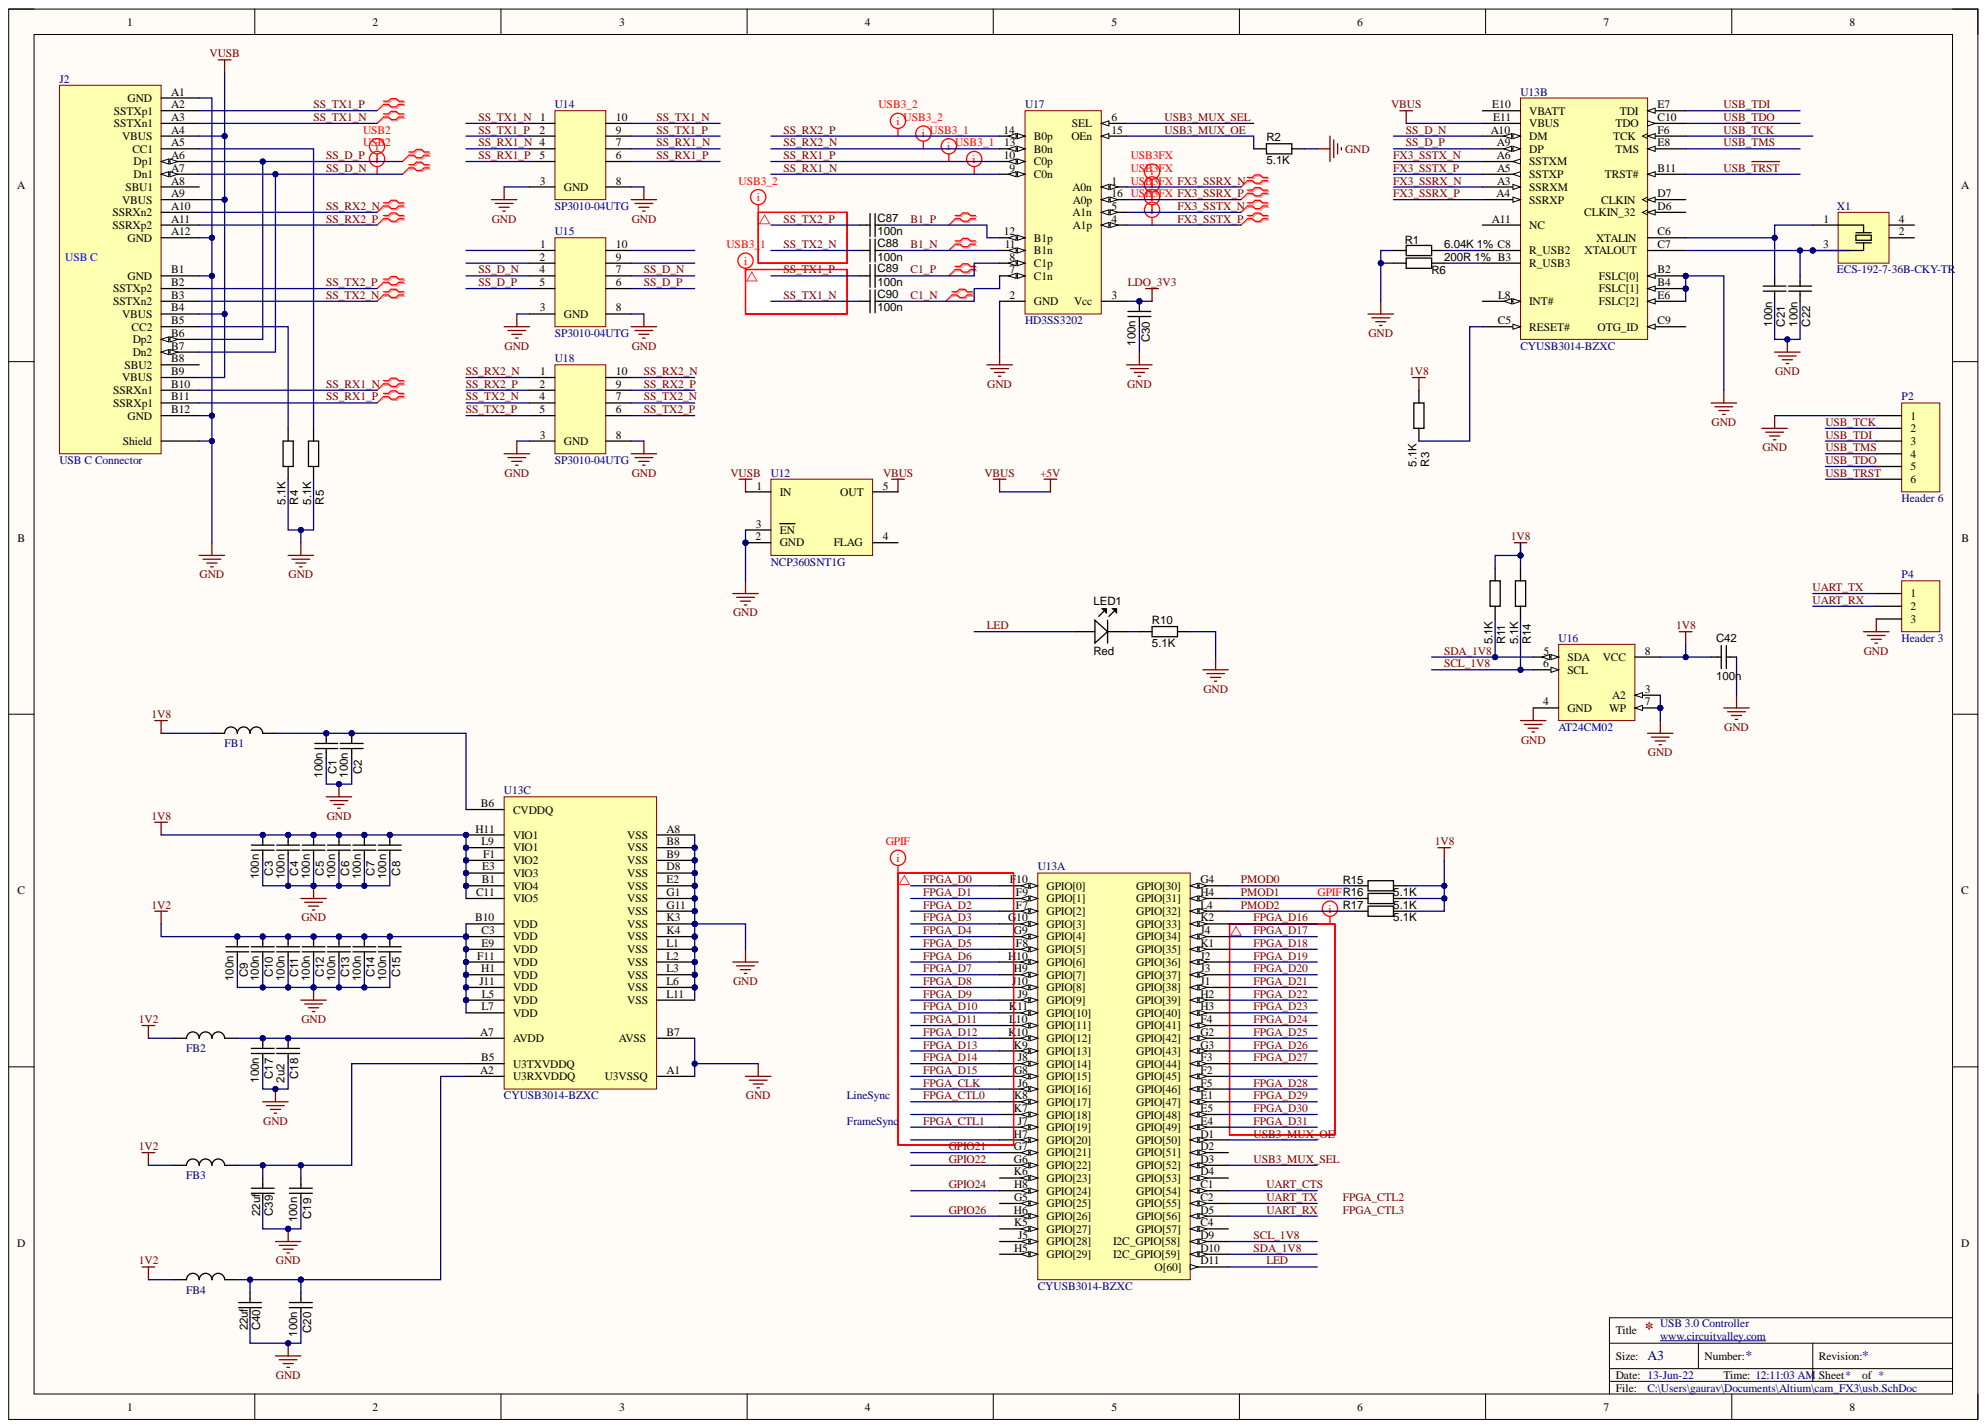
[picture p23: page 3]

Si ze: A | Number: * | Rev isi on: *

13-Jun-22 T i me: 12: 11:03 AM | | Shee t * o f *

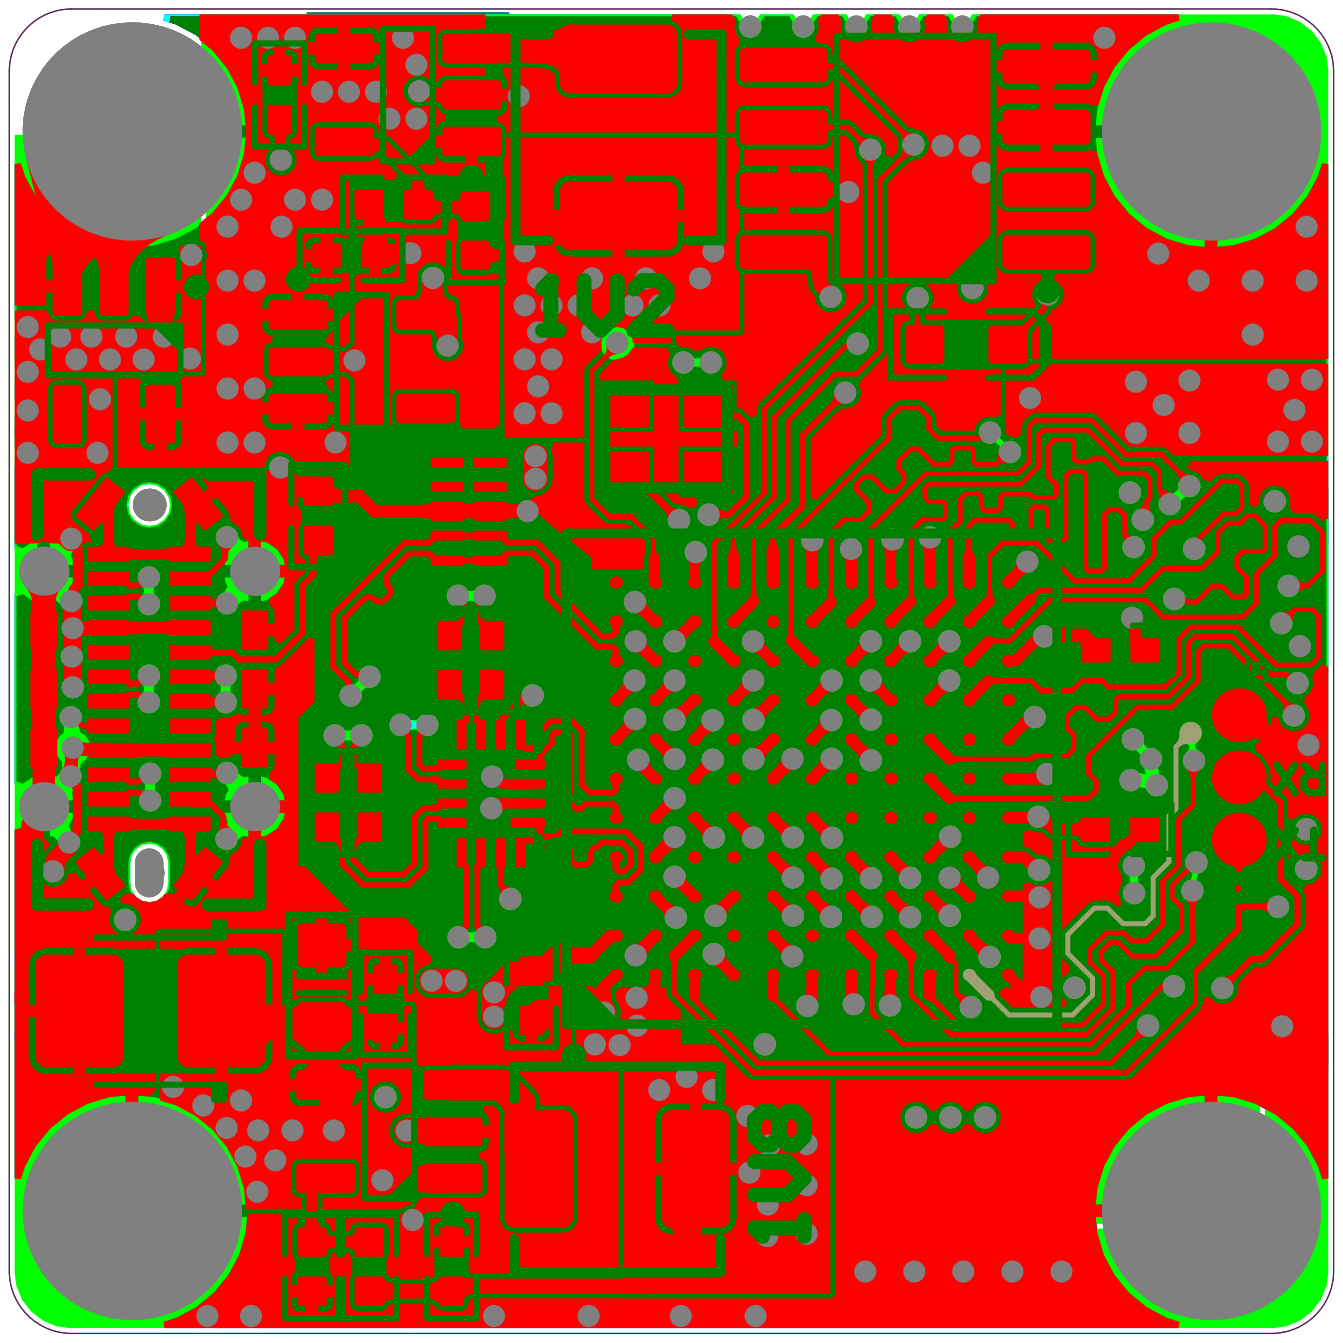
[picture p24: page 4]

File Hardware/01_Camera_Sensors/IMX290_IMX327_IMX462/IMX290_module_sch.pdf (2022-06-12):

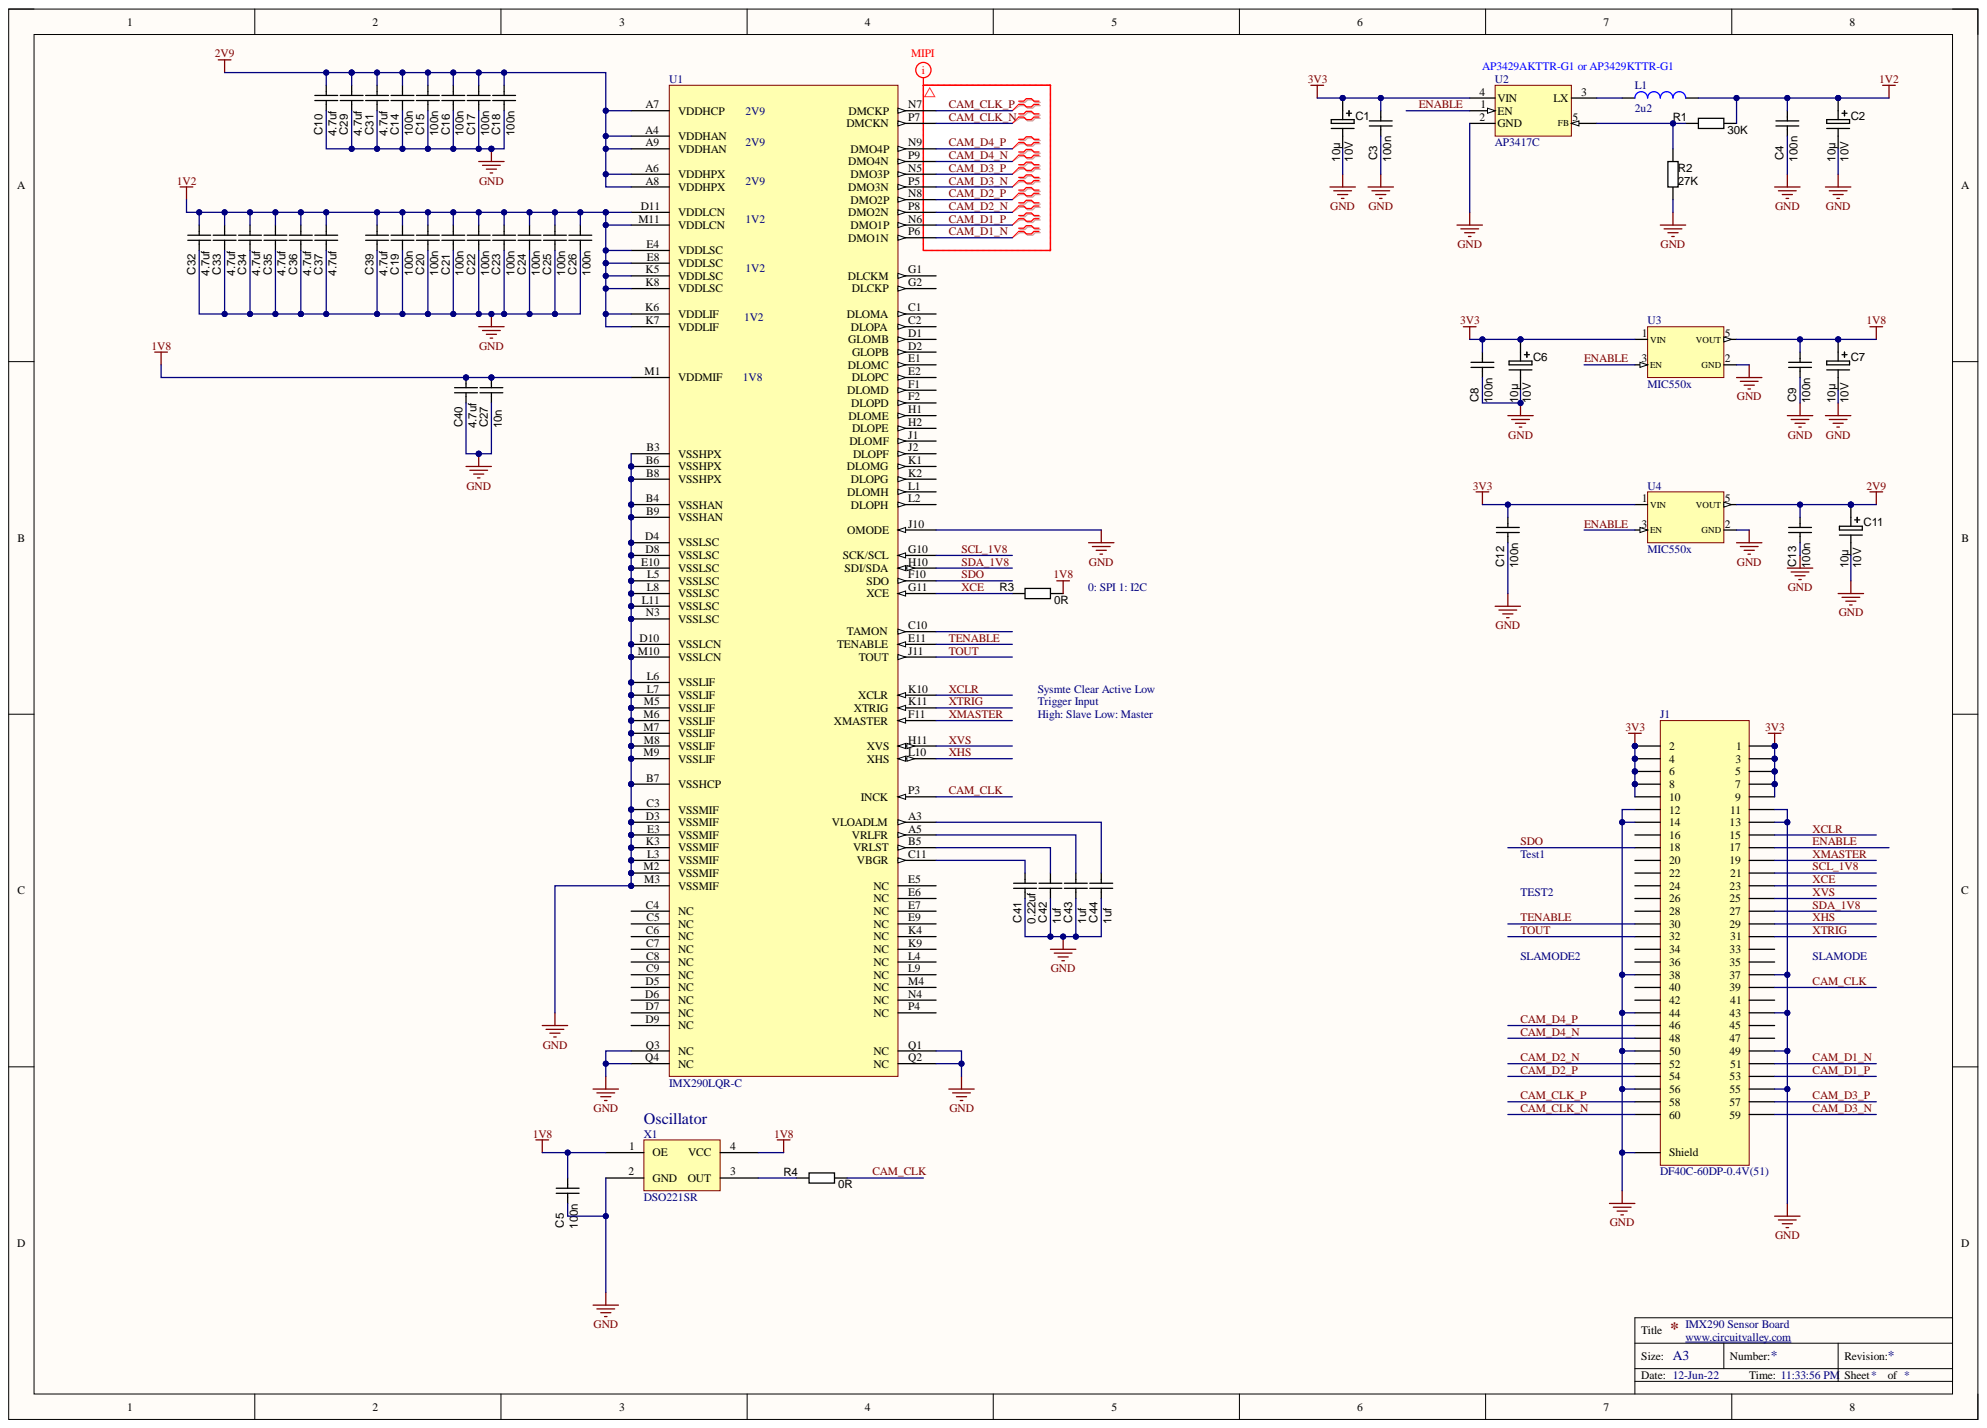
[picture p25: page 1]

Sysmte Clear Active Low
Trigger Input
High: Slave Low: Master

Size: A3 | Number: * | Revision: *

Date: 12-Jun-22 Time: 11:33:56 PM | | Sheet * of *

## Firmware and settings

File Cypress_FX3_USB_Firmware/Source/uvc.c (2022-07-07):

#include <cyu3system.h>
#include <cyu3os.h>
#include <cyu3dma.h>
#include <cyu3error.h>
#include <cyu3usb.h>
#include <cyu3uart.h>
#include <cyu3gpif.h>
#include <cyu3i2c.h>
#include <cyu3gpio.h>
#include <cyu3pib.h>
#include <cyu3utils.h>
#include <cyu3socket.h>

#include "uvc.h"

#include "camera_ptzcontrol.h"
#include "cyfxgpif2config.h"
#include "uvc_settings.h"
/*************************************************************************************************
                                         Global Variables
 *************************************************************************************************/
static CyU3PThread   uvcAppThread;                      /* UVC video streaming thread. */
static CyU3PThread   uvcAppEP0Thread;                   /* UVC control request handling thread. */
static CyU3PEvent    glFxUVCEvent;                      /* Event group used to signal threads. */
CyU3PDmaMultiChannel glChHandleUVCStream;               /* DMA multi-channel handle. */

/* Current UVC control request fields. See USB specification for definition. */
uint8_t  bmReqType, bRequest;                           /* bmReqType and bRequest fields. */
uint16_t wValue, wIndex, wLength;                       /* wValue, wIndex and wLength fields. */

CyU3PUSBSpeed_t usbSpeed = CY_U3P_NOT_CONNECTED;        /* Current USB connection speed. */
CyBool_t        streamingStarted = CyFalse;             /* Whether USB host has started streaming data */
CyBool_t        glIsApplnActive  = CyFalse;             /* When CLEAR_FEATURE (stop streaming) request is sent this variable is reset and set when start
                                                           streaming request is sent by Host. This is used during commit buffer failure event. */
static CyBool_t glIsConfigured = CyFalse;               /* Whether Application is in configured state or not */

/* Mac OS does not send EP Clear feature when the app is closed. It just stops issuing IN tokens. So buffer commit failures
 * can be counted and if it reaches beyond a limit, streaming can be stopped. Buffer commit failure code can be cleared
 * on DMA Consumer event so that the limit is not reached under streaming conditions.  */
static uint8_t glCommitBufferFailureCount = 0;

/*Variable to track whether the reason for DMA Reset is Frame Timer overflow or Commit Buffer Failure*/
static uint8_t glDmaResetFlag = CY_FX_UVC_DMA_RESET_EVENT_NOT_ACTIVE;

static uint8_t glUvcVcErrorCode = CY_FX_UVC_VC_ERROR_CODE_NO_ERROR;

#ifdef FRAME_TIMER_ENABLE

/* Maximum frame transfer time in milli-seconds. The value is updated for every resolution and frame rate.
 * Note: The value should always be greater than the frame blanking period */
uint16_t glFrameTimerPeriod = CY_FX_UVC_FRAME_TIMER_VAL_200MS;

/* Timer used to track frame transfer time. */
static CyU3PTimer UvcTimer;

/* Frame timer overflow call back function */
static void CyFxUvcAppProgressTimer(uint32_t arg)
{
    if(glDmaResetFlag == CY_FX_UVC_DMA_RESET_EVENT_NOT_ACTIVE)
    {
        glDmaResetFlag = CY_FX_UVC_DMA_RESET_FRAME_TIMER_OVERFLOW;
        CyU3PEventSet(&glFxUVCEvent, CY_FX_UVC_DMA_RESET_EVENT, CYU3P_EVENT_OR);
    }
}
#endif

#ifdef BACKFLOW_DETECT
uint8_t back_flow_detected = 0;                         /* Whether buffer overflow error is detected. */
#endif

#ifdef USB_DEBUG_INTERFACE
CyU3PDmaChannel  glDebugCmdChannel;                     /* Channel to receive debug commands on. */
CyU3PDmaChannel  glDebugRspChannel;                     /* Channel to send debug responses on. */
uint8_t         *glDebugRspBuffer;                      /* Buffer used to send debug responses. */
#endif

/* UVC Probe Control Settings for a USB 3.0 connection. */
uint8_t glProbeCtrl[CY_FX_UVC_MAX_PROBE_SETTING] = {
    0x00, 0x00,                 /* bmHint : no hit */
    0x01,                       /* Use 1st Video format index */
    0x01,                       /* Use 1st Video frame index */
    DBVAL(INTERVAL_30),     /* Desired frame interval in the unit of 100ns: 30 fps */
    0x00, 0x00,                 /* Key frame rate in key frame/video frame units: only applicable
                                   to video streaming with adjustable compression parameters */
    0x00, 0x00,                 /* PFrame rate in PFrame / key frame units: only applicable to
                                   video streaming with adjustable compression parameters */
    0x00, 0x00,                 /* Compression quality control: only applicable to video streaming
                                   with adjustable compression parameters */
    0x00, 0x00,                 /* Window size for average bit rate: only applicable to video
                                   streaming with adjustable compression parameters */
    0x00, 0x00,                 /* Internal video streaming i/f latency in ms */
    DBVAL(MAX_FRAME_SIZE),     /* Max video frame size in bytes */
    0x00, 0x80, 0x00, 0x00,      /* No. of bytes device can rx in single payload = 32 KB */

#ifndef FX3_UVC_1_0_SUPPORT
    /* UVC 1.1 Probe Control has additional fields from UVC 1.0 */
    0x00, 0x60, 0xE3, 0x16,             /* Device Clock */
    0x00,                               /* Framing Information - Ignored for uncompressed format*/
    0x00,                               /* Preferred payload format version */
    0x00,                               /* Minimum payload format version */
    0x00                                /* Maximum payload format version */
#endif
};

typedef struct __attribute__((packed)) uvc_control_s
{
	uint16_t hint;
	uint8_t format_index;
	uint8_t frame_index;
	uint32_t frame_interval;
	uint16_t key_frame_rate;
	uint16_t PFrame_rate;
	uint16_t comp_quality;
	uint16_t comp_win_size;
	uint16_t delay;
	uint32_t max_video_frame_size;
	uint32_t max_payload_transfer_size;
#ifndef FX3_UVC_1_0_SUPPORT
	uint32_t device_clock;
	uint8_t	frame_info;
	uint8_t prefered_version;
	uint8_t min_version;
	uint8_t max_version;
#endif
	uint8_t align_16[14];
}uvc_control_t;

/* UVC Probe Control Setting for a USB 2.0 connection. */
uint8_t glProbeCtrl20[CY_FX_UVC_MAX_PROBE_SETTING] = {
    0x00, 0x00,                 /* bmHint : no hit */
    0x01,                       /* Use 1st Video format index */
    0x01,                       /* Use 1st Video frame index */
    DBVAL(INTERVAL_30),    /* Desired frame interval in the unit of 100ns: 15 fps */
    0x00, 0x00,                 /* Key frame rate in key frame/video frame units: only applicable
                                   to video streaming with adjustable compression parameters */
    0x00, 0x00,                 /* PFrame rate in PFrame / key frame units: only applicable to
                                   video streaming with adjustable compression parameters */
    0x00, 0x00,                 /* Compression quality control: only applicable to video streaming
                                   with adjustable compression parameters */
    0x00, 0x00,                 /* Window size for average bit rate: only applicable to video
                                   streaming with adjustable compression parameters */
    0x00, 0x00,                 /* Internal video streaming i/f latency in ms */
    DBVAL(MAX_FRAME_SIZE),     /* Max video frame size in bytes */
    0x00, 0x80, 0x00, 0x00,      /* No. of bytes device can rx in single payload = 32 KB */

#ifndef FX3_UVC_1_0_SUPPORT
    /* UVC 1.1 Probe Control has additional fields from UVC 1.0 */
    0x00, 0x60, 0xE3, 0x16,             /* Device Clock */
    0x00,                               /* Framing Information - Ignored for uncompressed format*/
    0x00,                               /* Preferred payload format version */
    0x00,                               /* Minimum payload format version */
    0x00                                /* Maximum payload format version */
#endif
};

/* Video Probe Commit Control. This array is filled out when the host sends down the SET_CUR request. */
static uint8_t glCommitCtrl[CY_FX_UVC_MAX_PROBE_SETTING_ALIGNED];

/* Scratch buffer used for handling UVC class requests with a data phase. */
static uint8_t glEp0Buffer[32];

/* UVC Header to be prefixed at the top of each 16 KB video data buffer. */
uint8_t volatile glUVCHeader[CY_FX_UVC_MAX_HEADER] =
{
    0x0C,                               /* Header Length */
    0x8C,                               /* Bit field header field */
    0x00, 0x00, 0x00, 0x00,             /* Presentation time stamp field */
    0x00, 0x00, 0x00, 0x00, 0x00, 0x00  /* Source clock reference field */
};

#ifdef UVC_EXTENSION_UNIT

/* Format is: Version 1.0 (Major.Minor) Build date: 9/10/17 (MM/DD/YY) */
static uint8_t glFxUvcFirmwareVersion[5] = {
    1,       /* Major version */
    0,       /* Minor version */
    9,       /* Build month */
    22,      /* Build day */
    17       /* Build Year */
};
#endif

#ifdef DEBUG_PRINT_FRAME_COUNT
volatile static uint32_t glFrameCount = 0;              /* Number of video frames transferred so far. */
volatile static uint32_t glDmaDone = 1;                 /* Number of buffers transferred in the current frame. */
#endif
volatile static uint32_t gTotal_bytes = 0;

/* Add the UVC packet header to the top of the specified DMA buffer. */
void
CyFxUVCAddHeader (
        uint8_t *buffer_p,              /* Buffer pointer */
        uint8_t frameInd                /* EOF or normal frame indication */
        )
{
    /* Copy header to buffer */
    CyU3PMemCopy (buffer_p, (uint8_t *)glUVCHeader, CY_FX_UVC_MAX_HEADER);

    /* The EOF flag needs to be set if this is the last packet for this video frame. */
    if (frameInd & CY_FX_UVC_HEADER_EOF)
    {
        buffer_p[1] |= CY_FX_UVC_HEADER_EOF;
        glUVCHeader[1] ^= CY_FX_UVC_HEADER_FRAME_ID;
    }
}


/* Application Error Handler */
void
CyFxAppErrorHandler (
        CyU3PReturnStatus_t apiRetStatus    /* API return status */
        )
{
    /* This function is hit when we have hit a critical application error. This is not
       expected to happen, and the current implementation of this function does nothing
       except stay in a loop printing error messages through the UART port.

       This function can be modified to take additional error handling actions such
       as cycling the USB connection or performing a warm reset.
     */
    for (;;)
    {
        CyU3PDebugPrint (4, "Error handler...\r\n");
        CyU3PThreadSleep (1000);
    }
}

/* This function performs the operations for a Video Streaming Abort.
   This is called every time there is a USB reset, suspend or disconnect event.
 */
static void
CyFxUVCApplnAbortHandler (
        void)
{
    /* Set Video Stream Abort Event */
    CyU3PEventSet (&glFxUVCEvent, CY_FX_UVC_STREAM_ABORT_EVENT, CYU3P_EVENT_OR);
}

/* This is the Callback function to handle the USB Events */
static void
CyFxUVCApplnUSBEventCB (
        CyU3PUsbEventType_t evtype,  /* Event type */
        uint16_t             evdata  /* Event data */
        )
{
    switch (evtype)
    {
        case CY_U3P_USB_EVENT_SUSPEND:
            CyU3PDebugPrint (4, "UsbEventCB: SUSPEND encountered...\r\n");
            /* Set USB suspend Event */
            CyU3PEventSet (&glFxUVCEvent, CY_FX_USB_SUSPEND_EVENT_HANDLER, CYU3P_EVENT_OR);
            break;

        case CY_U3P_USB_EVENT_EP_UNDERRUN:
            CyU3PDebugPrint (4, "UsbEventCB: CY_U3P_USB_EVENT_EP_UNDERRUN encountered...\r\n");
            break;

        /* Intentional Fall-through all cases */
        case CY_U3P_USB_EVENT_SETCONF:
            if (CyU3PUsbGetSpeed() == CY_U3P_SUPER_SPEED)
            {
                CyU3PDebugPrint(4, "UsbEventCB: Detected SS USB Connection\r\n");
            }
            else if (CyU3PUsbGetSpeed() == CY_U3P_HIGH_SPEED)
            {
                CyU3PDebugPrint(4, "UsbEventCB: Detected HS USB Connection\r\n");
            }
        case CY_U3P_USB_EVENT_RESET:
        case CY_U3P_USB_EVENT_DISCONNECT:
        case CY_U3P_USB_EVENT_CONNECT:
            if (evtype == CY_U3P_USB_EVENT_SETCONF)
              glIsConfigured = CyTrue;
            else
              glIsConfigured = CyFalse;

            /* Stop the video streamer application and enable LPM. */
            CyU3PUsbLPMEnable();
            if (glIsApplnActive)
            {
              CyU3PDebugPrint(4, "UsbEventCB: Call App Stop\r\n");
              CyFxUVCApplnAbortHandler();
            }
            break;

        default:
            break;
    }
}

/* Callback to handle the USB Setup Requests and UVC Class events */
static CyBool_t
CyFxUVCApplnUSBSetupCB (
        uint32_t setupdat0, /* SETUP Data 0 */
        uint32_t setupdat1  /* SETUP Data 1 */
        )
{
    CyBool_t uvcHandleReq = CyFalse;
    uint32_t status;

    /* Obtain Request Type and Request */
    bmReqType = (uint8_t)(setupdat0 & CY_FX_USB_SETUP_REQ_TYPE_MASK);
    bRequest  = (uint8_t)((setupdat0 & CY_FX_USB_SETUP_REQ_MASK) >> 8);
    wValue    = (uint16_t)((setupdat0 & CY_FX_USB_SETUP_VALUE_MASK) >> 16);
    wIndex    = (uint16_t)(setupdat1 & CY_FX_USB_SETUP_INDEX_MASK);
    wLength   = (uint16_t)((setupdat1 & CY_FX_USB_SETUP_LENGTH_MASK) >> 16);

    /* Check for UVC Class Requests */
    switch (bmReqType)
    {
        case CY_FX_USB_UVC_GET_REQ_TYPE:
        case CY_FX_USB_UVC_SET_REQ_TYPE:
            /* UVC Specific requests are handled in the EP0 thread. */
            switch (wIndex & 0xFF)
            {
                case CY_FX_UVC_CONTROL_INTERFACE:
                    {
                        uvcHandleReq = CyTrue;
                        status = CyU3PEventSet (&glFxUVCEvent, CY_FX_UVC_VIDEO_CONTROL_REQUEST_EVENT, CYU3P_EVENT_OR);
                        if (status != CY_U3P_SUCCESS)
                        {
                            CyU3PDebugPrint (4, "Set CY_FX_UVC_VIDEO_CONTROL_REQUEST_EVENT Failed %x\r\n", status);
                            CyU3PUsbStall (0, CyTrue, CyFalse);
                        }
                    }
                    break;

                case CY_FX_UVC_STREAM_INTERFACE:
                    {
                        uvcHandleReq = CyTrue;
                        status = CyU3PEventSet (&glFxUVCEvent, CY_FX_UVC_VIDEO_STREAM_REQUEST_EVENT, CYU3P_EVENT_OR);
                        if (status != CY_U3P_SUCCESS)
                        {
                            /* Error handling */
                            CyU3PDebugPrint (4, "Set CY_FX_UVC_VIDEO_STREAM_REQUEST_EVENT Failed %x\r\n", status);
                            CyU3PUsbStall (0, CyTrue, CyFalse);
                        }
                    }
                    break;

                default:
                    break;
            }
            break;

        case CY_FX_USB_SET_INTF_REQ_TYPE:
            if (bRequest == CY_FX_USB_SET_INTERFACE_REQ)
            {
                /* Some hosts send Set Interface Alternate Setting 0 command while stopping the video
                 * stream. The application uses this event to stop streaming. */
                if ((wIndex == CY_FX_UVC_STREAM_INTERFACE) && (wValue == 0))
                {
                    /* Stop GPIF state machine to stop data transfers through FX3 */
                    CyU3PDebugPrint (4, "Alternate setting 0..\r\n");

                    /* Clear the stall condition and sequence numbers. */
                    CyU3PUsbStall (CY_FX_EP_BULK_VIDEO, CyFalse, CyTrue);
                    CyFxUVCApplnAbortHandler ();

                    uvcHandleReq = CyTrue;
                    /* Complete Control request handshake */
                    CyU3PUsbAckSetup ();
                }
            }
            else if ((bRequest == CY_U3P_USB_SC_SET_FEATURE) || (bRequest == CY_U3P_USB_SC_CLEAR_FEATURE))
            {
                CyU3PDebugPrint(4, "USBSetupCB:In SET_FTR %d::%d\r\n", glIsApplnActive, glIsConfigured);
                if (glIsConfigured)
                {
                    uvcHandleReq = CyTrue;
                    CyU3PUsbAckSetup ();
                }
            }

            break;

        case CY_U3P_USB_TARGET_ENDPT:
            if (bRequest == CY_U3P_USB_SC_CLEAR_FEATURE)
            {
                if (wIndex == CY_FX_EP_BULK_VIDEO)
                {
                    /* Windows OS sends Clear Feature Request after it stops streaming,
                     * however MAC OS sends clear feature request right after it sends a
                     * Commit -> SET_CUR request. Hence, stop the video streaming and clear
                     * the stall condition and sequence numbers */
                    CyU3PDebugPrint (4, "Clear feature request detected...\r\n");

                    /* Clear the stall condition and sequence numbers. */
                    CyU3PUsbStall (CY_FX_EP_BULK_VIDEO, CyFalse, CyTrue);
                    CyFxUVCApplnAbortHandler();

                    uvcHandleReq = CyTrue;
                    /* Complete Control request handshake */
                    CyU3PUsbAckSetup ();
                }
            }
            break;

        default:
            break;
    }

    /* Return status of request handling to the USB driver */
    return uvcHandleReq;
}

/* DMA callback providing notification when data buffers are received from the sensor and when they have
 * been drained by the USB host.
 *
 * The UVC headers are attached to the data, and forwarded to the USB host in this callback function.
 */
void
CyFxUvcApplnDmaCallback (
        CyU3PDmaMultiChannel *chHandle,
        CyU3PDmaCbType_t      type,
        CyU3PDmaCBInput_t    *input
        )
{
    CyU3PDmaBuffer_t    dmaBuffer;
    CyU3PReturnStatus_t status = CY_U3P_SUCCESS;





    if (type == CY_U3P_DMA_CB_PROD_EVENT)
    {
        /* This is a produce event notification to the CPU. This notification is received upon reception of
         * every buffer. The buffer will not be sent out unless it is explicitly committed. The call shall fail
         * if there is a bus reset / usb disconnect or if there is any application error.
         */

#ifdef FRAME_TIMER_ENABLE
        /* Received data from the sensor so stop the frame timer */
        CyU3PTimerStop(&UvcTimer);

        /* Restart the frame timer so that we receive the next buffer before timer overflows */
        CyU3PTimerModify(&UvcTimer, glFrameTimerPeriod, 0);
        CyU3PTimerStart(&UvcTimer);
#endif

        /* There is a possibility that CyU3PDmaMultiChannelGetBuffer will return CY_U3P_ERROR_INVALID_SEQUENCE here.
         * In such a case, do nothing. We make up for this missed produce event by making repeated commit actions
         * in subsequent produce event callbacks.
         */
        status = CyU3PDmaMultiChannelGetBuffer (chHandle, &dmaBuffer, CYU3P_NO_WAIT);
        while (status == CY_U3P_SUCCESS)
        {
        	CyU3PReturnStatus_t apiRetStatus = CY_U3P_SUCCESS;
        	gTotal_bytes = gTotal_bytes + dmaBuffer.count;

        	apiRetStatus = CyU3PGpioSetValue (DEBUG1_GPIO, CyFalse);
        	if (apiRetStatus != CY_U3P_SUCCESS)
        	{
        		CyU3PDebugPrint (4, "GPIO Set Value Error, Error Code = %d\n", apiRetStatus);
        		return;
        	}

        	//Wait for some time to allow proper reset.

        	// Drive the GPIO high to bring the sensor out of reset.
        	apiRetStatus = CyU3PGpioSetValue (DEBUG1_GPIO, CyTrue);
        	if (apiRetStatus != CY_U3P_SUCCESS)
        	{
        		CyU3PDebugPrint (4, "GPIO Set Value Error, Error Code = %d\n", apiRetStatus);
        		return;
        	}

            /* Add Headers*/
            if (dmaBuffer.count == CY_FX_UVC_BUF_FULL_SIZE)
            {
                /* A full buffer indicates there is more data to go in this video frame. */
                CyFxUVCAddHeader (dmaBuffer.buffer - CY_FX_UVC_MAX_HEADER, CY_FX_UVC_HEADER_FRAME);
            }
            else
            {
                /* A partially filled buffer indicates the end of the ongoing video frame. */
                CyFxUVCAddHeader (dmaBuffer.buffer - CY_FX_UVC_MAX_HEADER, CY_FX_UVC_HEADER_EOF);

               	//CyU3PDebugPrint (4, "t %d\n", gTotal_bytes);
                  //              	gTotal_bytes =0;
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
int
main (
        void)
{
    CyU3PReturnStatus_t apiRetStatus;
    CyU3PIoMatrixConfig_t io_cfg;

    CyU3PSysClockConfig_t clk_cfg;
    /* Initialize the device */
    clk_cfg.setSysClk400  = CyTrue;
    clk_cfg.cpuClkDiv     = 2;
    clk_cfg.dmaClkDiv     = 2;
    clk_cfg.mmioClkDiv    = 2;
    clk_cfg.useStandbyClk = CyFalse;
    clk_cfg.clkSrc        = CY_U3P_SYS_CLK;
    apiRetStatus = CyU3PDeviceInit (&clk_cfg);
    if (apiRetStatus != CY_U3P_SUCCESS)
    {
        goto handle_fatal_error;
    }

    /* Turn on instruction cache to improve firmware performance. Use Release build to improve it further */
    apiRetStatus = CyU3PDeviceCacheControl (CyTrue, CyFalse, CyFalse);

    /* Configure the IO matrix for the device. */
    io_cfg.isDQ32Bit        = CyTrue;
    io_cfg.s0Mode       	= CyFalse;
    io_cfg.s1Mode	        = CyFalse;
    io_cfg.lppMode          = CY_U3P_IO_MATRIX_LPP_DEFAULT;
    io_cfg.gpioSimpleEn[0]  = 0;
    io_cfg.gpioSimpleEn[1]  = 0;
    io_cfg.gpioComplexEn[0] = 0;
    io_cfg.gpioComplexEn[1] = 0;
    io_cfg.useUart          = CyTrue;   /* Uart is enabled for logging. */
    io_cfg.useI2C           = CyTrue;   /* I2C is used for the sensor interface. */
    io_cfg.useI2S           = CyFalse;
    io_cfg.useSpi           = CyFalse;

    apiRetStatus = CyU3PDeviceConfigureIOMatrix (&io_cfg);
    if (apiRetStatus != CY_U3P_SUCCESS)
    {
        goto handle_fatal_error;
    }

    /* This is a non returnable call for initializing the RTOS kernel */
    CyU3PKernelEntry ();

    /* Dummy return to make the compiler happy */
    return 0;

handle_fatal_error:
    /* Cannot recover from this error. */
    while (1);
}

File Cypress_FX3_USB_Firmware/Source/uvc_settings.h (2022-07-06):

/*
 * uvc_settings.h
 *
 *  Created on: Jan 25, 2020
 *      Author: gaurav
 */

#ifndef UVC_SETTINGS_H_
#define UVC_SETTINGS_H_


#include "sensor_imx477.h" 	//Current driver state allow one sensor file to be included at once.
//#include "sensor_imx219.h"

#define WBVAL(x) (x & 0xFF),((x >> 8) & 0xFF)
#define DBVAL(x) (x & 0xFF),((x >> 8) & 0xFF),((x >> 16) & 0xFF),((x >> 24) & 0xFF)

#define UVC_MODE0_WIDTH								(unsigned int)SENSOR_MODE0_WIDTH
#define UVC_MODE0_HEIGHT							(unsigned int)SENSOR_MODE0_HEIGHT
#define UVC_MODE0_FPS								(unsigned int)SENSOR_MODE0_FPS
#define MIN_MODE0_BIT_RATE							(unsigned long)(UVC_MODE0_WIDTH*UVC_MODE0_HEIGHT*16*UVC_MODE0_FPS) //YUY2 4byte per 2 pixel
#define MAX_MODE0_BIT_RATE							(unsigned long)(UVC_MODE0_WIDTH*UVC_MODE0_HEIGHT*16*UVC_MODE0_FPS)
#define MAX_MODE0_FRAME_SIZE						(unsigned long)(UVC_MODE0_WIDTH*UVC_MODE0_HEIGHT*2)//YUY2 4byte per 2 pixel
#define INTERVAL_MODE0								(unsigned long)(10000000/UVC_MODE0_FPS)

#define UVC_MODE1_WIDTH								(unsigned int)SENSOR_MODE1_WIDTH
#define UVC_MODE1_HEIGHT							(unsigned int)SENSOR_MODE1_HEIGHT
#define UVC_MODE1_FPS								(unsigned int)SENSOR_MODE1_FPS
#define MIN_MODE1_BIT_RATE							(unsigned long)(UVC_MODE1_WIDTH*UVC_MODE1_HEIGHT*16*UVC_MODE1_FPS) //YUY2 4byte per 2 pixel
#define MAX_MODE1_BIT_RATE							(unsigned long)(UVC_MODE1_WIDTH*UVC_MODE1_HEIGHT*16*UVC_MODE1_FPS)
#define MAX_MODE1_FRAME_SIZE						(unsigned long)(UVC_MODE1_WIDTH*UVC_MODE1_HEIGHT*2)//YUY2 4byte per 2 pixel
#define INTERVAL_MODE1								(unsigned long)(10000000/UVC_MODE1_FPS)

#define UVC_MODE2_WIDTH								(unsigned int)SENSOR_MODE2_WIDTH
#define UVC_MODE2_HEIGHT							(unsigned int)SENSOR_MODE2_HEIGHT
#define UVC_MODE2_FPS								(unsigned int)SENSOR_MODE2_FPS
#define MIN_MODE2_BIT_RATE							(unsigned long)(UVC_MODE2_WIDTH*UVC_MODE2_HEIGHT*16*UVC_MODE2_FPS) //YUY2 4byte per 2 pixel
#define MAX_MODE2_BIT_RATE							(unsigned long)(UVC_MODE2_WIDTH*UVC_MODE2_HEIGHT*16*UVC_MODE2_FPS)
#define MAX_MODE2_FRAME_SIZE						(unsigned long)(UVC_MODE2_WIDTH*UVC_MODE2_HEIGHT*2)//YUY2 4byte per 2 pixel
#define INTERVAL_MODE2								(unsigned long)(10000000/UVC_MODE2_FPS)

#define UVC_MODE3_WIDTH								(unsigned int)SENSOR_MODE3_WIDTH
#define UVC_MODE3_HEIGHT							(unsigned int)SENSOR_MODE3_HEIGHT
#define UVC_MODE3_FPS								(unsigned int)SENSOR_MODE3_FPS
#define MIN_MODE3_BIT_RATE							(unsigned long)(UVC_MODE3_WIDTH*UVC_MODE3_HEIGHT*16*UVC_MODE3_FPS) //YUY2 4byte per 2 pixel
#define MAX_MODE3_BIT_RATE							(unsigned long)(UVC_MODE3_WIDTH*UVC_MODE3_HEIGHT*16*UVC_MODE3_FPS)
#define MAX_MODE3_FRAME_SIZE						(unsigned long)(UVC_MODE3_WIDTH*UVC_MODE3_HEIGHT*2)//YUY2 4byte per 2 pixel
#define INTERVAL_MODE3								(unsigned long)(10000000/UVC_MODE3_FPS)

#define UVC_MODE4_WIDTH								(unsigned int)SENSOR_MODE4_WIDTH
#define UVC_MODE4_HEIGHT							(unsigned int)SENSOR_MODE4_HEIGHT
#define UVC_MODE4_FPS_MIN							(unsigned int)SENSOR_MODE4_FPS_MIN
#define UVC_MODE4_FPS								(unsigned int)SENSOR_MODE4_FPS
#define MIN_MODE4_BIT_RATE							(unsigned long)(UVC_MODE4_WIDTH*UVC_MODE4_HEIGHT*16*UVC_MODE4_FPS_MIN) //YUY2 4byte per 2 pixel
#define MAX_MODE4_BIT_RATE							(unsigned long)(UVC_MODE4_WIDTH*UVC_MODE4_HEIGHT*16*UVC_MODE4_FPS)
#define MAX_MODE4_FRAME_SIZE						(unsigned long)(UVC_MODE4_WIDTH*UVC_MODE4_HEIGHT*2)//YUY2 4byte per 2 pixel
#define INTERVAL_MODE4_MIN							(unsigned long)(10000000/UVC_MODE4_FPS_MIN)
#define INTERVAL_MODE4								(unsigned long)(10000000/UVC_MODE4_FPS)

#define INTERVAL_30									(unsigned long)(10000000/30)
#define MAX_FRAME_SIZE                              (unsigned long)(UVC_MODE4_WIDTH*UVC_MODE4_HEIGHT*2)//yuy2

typedef enum
{
	FRAME_MODE0 = 1,
	FRAME_MODE1,
	FRAME_MODE2,
	FRAME_MODE3,
	FRAME_MODE4,
}frame_t;

#endif /* UVC_SETTINGS_H_ */

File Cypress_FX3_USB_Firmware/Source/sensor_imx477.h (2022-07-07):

/*
 * sensor_imx477.h
 *
 *  Created on: Jun 24, 2022
 *      Author: gaurav
 */


#ifndef _IMX477MIPI_SENSOR_H
#define _IMX477MIPI_SENSOR_H

#include <cyu3types.h>
#include <stdbool.h>


#define SENSOR_ADDR_WR 0x34             /* Slave address used to write sensor registers. */
#define SENSOR_ADDR_RD 0x35             /* Slave address used to read from sensor registers. */
#define I2C_SLAVEADDR_MASK 0xFE         /* Mask to get actual I2C slave address value without direction bit. */

/* GPIO 22 on FX3 is used to reset the Image sensor. */
#define DEBUG1_GPIO 		23
#define DEBUG_GPIO 			27
#define SENSOR_RESET_GPIO 	22

#define _countof(array) (sizeof(array) / sizeof(array[0]))

#define GET_WORD_MSB(x)  ((x >> 8) & 0xFF)
#define GET_WORD_LSB(x)  (		 x & 0xFF)

#define IMX477_SENSOR_ID			0x0477

#define CAMERA_ID 					IMX477_SENSOR_ID

#define REG_SW_RESET 				0x0103
#define REG_MODEL_ID_MSB			0x0016 //also 0x0000
#define REG_MODEL_ID_LSB			0x0017 //also 0x0001
#define REG_MODE_SEL 				0x0100
#define REG_CSI_LANE				0x0114
#define REG_DPHY_CTRL				0x0808
#define REG_EXCK_FREQ_MSB			0x0136
#define REG_EXCK_FREQ_LSB			0x0137
#define REG_FRAME_LEN_MSB			0x0340
#define REG_FRAME_LEN_LSB			0x0341
#define REG_LINE_LEN_MSB			0x0342
#define REG_LINE_LEN_LSB			0x0343
#define REG_X_ADD_STA_MSB			0x0344
#define REG_X_ADD_STA_LSB			0x0345
#define REG_X_ADD_END_MSB			0x0348
#define REG_X_ADD_END_LSB			0x0349
#define REG_Y_ADD_STA_MSB			0x0346
#define REG_Y_ADD_STA_LSB			0x0347
#define REG_Y_ADD_END_MSB			0x034A
#define REG_Y_ADD_END_LSB			0x034B

#define REG_X_OUT_SIZE_MSB			0x034C
#define REG_X_OUT_SIZE_LSB			0x034D
#define REG_Y_OUT_SIZE_MSB			0x034E
#define REG_Y_OUT_SIZE_LSB			0x034F


#define REG_IMG_ORIENT				0x0101
#define REG_BINNING_MODE			0x0900
#define REG_BINNING_HV				0x0901 //Very Diff

#define REG_BINNING_WEIGHTING		0x0902
//#define REG_BIN_CALC_MOD_H			0x0176
//#define REG_BIN_CALC_MOD_V			0x0177

#define REG_CSI_FORMAT_C			0x0112		//0x08-> 8 bit 0x0A-> 10bit 0xC ->12bit
#define REG_CSI_FORMAT_D			0x0113

#define REG_ANA_GAIN_GLOBAL_MSB 		0x0204
#define REG_ANA_GAIN_GLOBAL_LSB 		0x0205

#define REG_ANA_GAIN_GLOBAL1_MSB		0x00F0
#define REG_ANA_GAIN_GLOBAL1_LSB		0x00F1
#define REG_ANA_GAIN_GLOBAL2_MSB		0x00F2
#define REG_ANA_GAIN_GLOBAL2_LSB		0x00F3
#define REG_ANA_GAIN_GLOBAL3_MSB		0x00F4
#define REG_ANA_GAIN_GLOBAL3_LSB		0x00F5

#define REG_DIG_GAIN_GLOBAL1_MSB		0x00F6
#define REG_DIG_GAIN_GLOBAL1_LSB		0x00F7
#define REG_DIG_GAIN_GLOBAL2_MSB		0x00F8
#define REG_DIG_GAIN_GLOBAL2_LSB		0x00F9
#define REG_DIG_GAIN_GLOBAL3_MSB		0x00FA
#define REG_DIG_GAIN_GLOBAL3_LSB		0x00FB

#define REG_FINE_INTEGRATION_TIME_MSB	0x0200
#define REG_FINE_INTEGRATION_TIME_LSB 	0x0201
#define REG_COARSE_INTEGRATION_TIME_MSB	0x0202
#define REG_COARSE_INTEGRATION_TIME_LSB 0x0203

#define REG_IVTPXCK_DIV				0x0301
#define REG_IVTSYCK_DIV				0x0303

#define REG_IOP_PREPLLCK_DIV		0x030D
#define	REG_IVT_PREPLLCK_DIV		0x0305
#define	REG_PLL_IVT_MPY_MSB			0x0306
#define	REG_PLL_IVT_MPY_LSB			0x0307
#define REG_IOPPXCK_DIV				0x0309
#define REG_IOPSYCK_DIV				0x030B

#define REG_IOP_MPY_MSB				0x030E
#define REG_IOP_MPY_LSB				0x030F
#define REG_PLL_MULTI_DRV			0x0310

#define REG_TEST_PATTERN_MSB		0x0600
#define REG_TEST_PATTERN_LSB		0x0601
#define REG_TP_RED_MSB				0x0602
#define REG_TP_RED_LSB				0x0603
#define REG_TP_GREENR_MSB			0x0604
#define REG_TP_GREENR_LSB			0x0605
#define REG_TP_BLUE_MSB				0x0606
#define REG_TP_BLUE_LSB				0x0607
#define REG_TP_GREENB_MSB			0x0608
#define REG_TP_GREENB_LSB			0x0609
//#define	REG_TP_X_OFFSET_MSB			0x0620
//#define	REG_TP_X_OFFSET_LSB			0x0621
//#define	REG_TP_Y_OFFSET_MSB			0x0622
//#define	REG_TP_Y_OFFSET_LSB			0x0623
//#define	REG_TP_WIDTH_MSB			0x0624
//#define	REG_TP_WIDTH_LSB			0x0625
//#define	REG_TP_HEIGHT_MSB			0x0626
//#define	REG_TP_HEIGHT_LSB			0x0627
#define REG_FRAME_BLANKSTOP_CTRL	0xE000 //whether to go out of HS and into LP mode while frame blank happen

#define REG_PD_AREA_WIDTH_MSB		0x38A8
#define REG_PD_AREA_WIDTH_LSB		0x38A9
#define REG_PD_AREA_HEIGHT_MSB		0x38AA
#define REG_PD_AREA_HEIGHT_LSB		0x38AB

#define REG_FRAME_LENGTH_CTRL		0x0350
#define REG_EBD_SIZE_V				0xBCF1
#define REG_DPGA_GLOBEL_GAIN		0x3FF9

#define REG_X_ENV_INC_CONST			0x0381
#define REG_X_ODD_INC_CONST			0x0383
#define REG_Y_ENV_INC_CONST			0x0385
#define REG_Y_ODD_INC				0x0387


#define REG_MULTI_CAM_MODE			0x3F0B
#define REG_ADC_BIT_SETTING			0x3F0D

#define REG_SCALE_MODE				0x0401
#define REG_SCALE_M_MSbit			0x0404
#define REG_SCALE_M_LSB				0x0405
#define REG_SCALE_N_MSbit			0x0406
#define REG_SCALE_N_LSB				0x0407

#define REG_DIG_CROP_X_OFFSET_MSB	0x0408
#define REG_DIG_CROP_X_OFFSET_LSB	0x0409
#define REG_DIG_CROP_Y_OFFSET_MSB	0x040A
#define REG_DIG_CROP_Y_OFFSET_LSB	0x040B
#define REG_DIG_CROP_WIDTH_MSB		0x040C
#define REG_DIG_CROP_WIDTH_LSB		0x040D
#define REG_DIG_CROP_HEIGHT_MSB		0x040E
#define REG_DIG_CROP_HEIGHT_LSB		0x040F

#define REG_REQ_LINK_BIT_RATE_MSB	0x0820
#define REG_REQ_LINK_BIT_RATE_LMSB	0x0821
#define REG_REQ_LINK_BIT_RATE_MLSB	0x0822
#define REG_REQ_LINK_BIT_RATE_LSB	0x0823

#define REG_TCLK_POST_EX_MSB		0x080A
#define REG_TCLK_POST_EX_LSB		0x080B
#define REG_THS_PRE_EX_MSB			0x080C
#define REG_THS_PRE_EX_LSB			0x080D
#define REG_THS_ZERO_MIN_MSB		0x080E
#define REG_THS_ZERO_MIN_LSB		0x080F
#define REG_THS_TRAIL_EX_MSB		0x0810
#define REG_THS_TRAIL_EX_LSB		0x0811
#define REG_TCLK_TRAIL_MIN_MSB		0x0812
#define REG_TCLK_TRAIL_MIN_LSB		0x0813
#define REG_TCLK_PREP_EX_MSB		0x0814
#define REG_TCLK_PREP_EX_LSB		0x0815
#define REG_TCLK_ZERO_EX_MSB		0x0816
#define REG_TCLK_ZERO_EX_LSB		0x0817
#define REG_TLPX_EX_MSB				0x0818
#define REG_TLPX_EX_LSB				0x0819

#define REG_PDAF_CTRL1_0			0x3E37
#define REG_POWER_SAVE_ENABLE		0x3F50

#define REG_LINE_LEN_INCLK_MSB		0x3F56
#define REG_LINE_LEN_INCLK_LSB		0x3F57

#define REG_MAP_COUPLET_CORR		0x0B05
#define REG_SING_DYNAMIC_CORR		0x0B06
#define REG_CIT_LSHIFT_LONG_EXP		0x3100

#define REG_TEMP_SENS_CTL 			0x0138

#define REG_DOL_HDR_EN				0x00E3
#define REG_DOL_HDR_NUM				0x00E4
#define REG_DOL_CSI_DT_FMT_H_2ND	0x00FC
#define REG_DOL_CSI_DT_FMT_L_2ND	0x00FD
#define REG_DOL_CSI_DT_FMT_H_3ND	0x00FE
#define REG_DOL_CSI_DT_FMT_L_3ND	0x00FF
#define REG_DOL_CONST				0xE013


#define LANES 2
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

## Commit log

2022-06-12 Added Camera Mount files
    [C mount v1.f3d, C mount v1.step]
2022-06-12 USB Controller Hardware files and source along with gerber added
    [cam_FX3.PrjPcb, camera.SchDoc, power.SchDoc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]
2022-06-12 Added FPGA PCB Source ,Gerber
    [FPGA_Core_FX3.PrjPcb, fpga_flash.SchDoc, fpga_gpif.SchDoc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]
2022-06-12 Added IMX290 IMX327 IMX462 PCB source and gerber
    [IMX290_Module.PrjPcb, IMX290_module_pcb.PcbDoc, IMX290_module_sch.SchDoc]
2022-06-12 Added PCB Images
2022-06-13 Added USB controller firmware with USB C reversal support
    [camera_ptzcontrol.h, sensor_imx219.c, sensor_imx219.h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]
2022-07-01 Fixed pin mapping to represent hardware
2022-07-04 Added IMX477 Camera Driver in 10bit and also 12bit mode
2022-07-06 UVC descriptor was changed to support easy sensor section
2022-07-06 IMX477 Driver changes to support easy lane change and support multi sensor
2022-07-06 Minor changes to support change of number for lanes, Need work for easy sensor change
2022-07-06 IMX219 Driver changed to adapt quick camera sensor change.
2022-07-07 Fixed Full Frame 5 FPS mode
    [sensor_imx477.c]
2022-07-07 UVC Gain controls fixes
    [sensor_imx219.c, sensor_imx219.h]
2022-07-08 IMX290 Basic Driver
2022-07-11 Camera controller, Sample Generator Frame detector
2022-07-11 Pin assignment for few modules
2022-07-11 Added support for Sample generator camera controller frame detector
2022-07-11 added Sample generator ROM file
2022-07-11 Added config files for IP blocks
    [csi_dphy.cfg, dphy_dummy.cfg, line_ram_dp.cfg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]
2022-07-11 Moved IP and there files
    [csi_dphy.cfg, dphy_dummy.cfg, line_ram_dp.cfg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]
2022-10-16 Added BOM lists with BOM cost information
    [Cam_FX3_BOM.xlsx, FPGA_Core_Crosslink_BOM.xlsx, IMX290_Module_BOM.xlsx]
2022-10-16 IMX477 Sensor PCB Added
    [IMX477.PrjPcb, imx477.PcbDoc, imx477_sensor.SchDoc]
2022-11-01 Fixed 4 Lane 8 gear Packet decoder
2022-11-01 Fixed 2 Lane 8x Gear decoder
2022-11-01 Fixed 2 Lane 2PPC 8x Gear decoder
2022-11-01 Fixed 4 Lane 8x Gear depacker
2022-11-01 Added 4 Lane 8 Gear 8 PPC depacker
2023-01-14 Added missing camera connector schematic file
    [camera.SchDoc]
2023-10-22 Changed Clock Domain For Debayer Filter
2023-10-22 Fixed XCE Pin on Camera controller
2023-10-22 Clock Domain Fixed in Sample generator
2026-03-27 Update README with new camera version details
    Added information about the new CHC5 Open Source Camera version and included a YouTube link with an image.
2026-03-27 Fix header formatting for CHC5 camera announcement
2026-09-13 Update README with new camera version announcement
2026-09-13 Fix formatting in README for new camera version announcement
2026-09-13 Fix formatting and update camera availability notice
2026-09-13 Update announcement for CHC5 Open Source Camera
2026-09-13 Revise caution note to tip for CHC5 camera
    Updated caution note to a tip for the new camera version.
2026-09-13 Update README to reflect new camera version availability
2026-09-13 Update tip formatting for new camera version notice

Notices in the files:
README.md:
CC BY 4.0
